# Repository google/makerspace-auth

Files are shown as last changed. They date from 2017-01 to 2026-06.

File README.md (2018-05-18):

# Summary

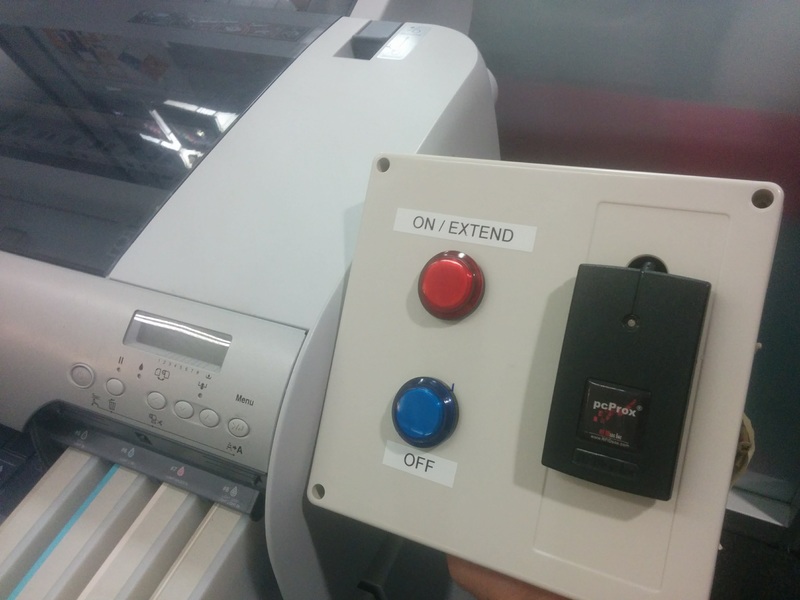
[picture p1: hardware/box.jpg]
Sample controller box


We started this project with two goals in mind, for Google makerspaces where
employees all have the same kind of RFID badge:

1. Only people authorized (trained) should be able to use dangerous tools
2. We'd like to have reliable access logs for even non-dangerous tools

## Organization

    docs/
      Documentation on the project to include contributions on tool connectivity.
    software/
      The Python client that runs on a Pi.
    hardware/
      The custom Pi hat we use to interact with buttons and a power switch tail.

## Contributing

We *welcome* contributions, especially ones that make this more useful to other
makerspaces.  We'd like this to be a generic solution wherever possible.

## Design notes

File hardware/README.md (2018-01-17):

The job of the hardware board is adapt a commodity board to customizable buttons
and actuators.  Currently there is only one board:

## Pi Hat 1
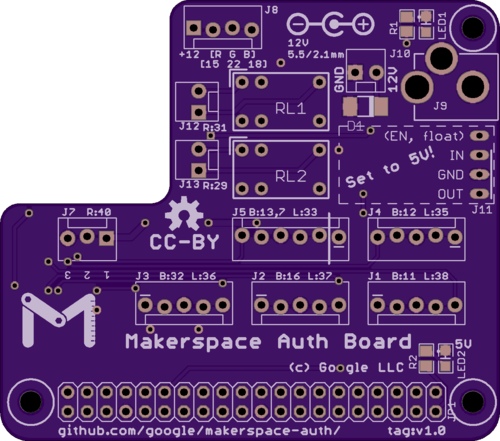
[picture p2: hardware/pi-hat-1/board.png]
Board image


A custom Pi hat which is pretty simple to build (we held intro soldering classes
around it).  The board takes 12V in, powers the Pi under it, and switches 12V
for lights on buttons (up to six of them), a high-current output for external
relays, and two small relays intended for volt-free switching.

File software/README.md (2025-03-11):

# Software

For the basic walkthrough of how this code works, see https://google.github.io/makerspace-auth/client/Walkthrough.html

Prerequisites:

1. Python 2.7 or 3.6+
1. `evdev` (On Raspberry Pi OS, you can install with `sudo apt install python3-evdev`)
1. `gpiozero` module
1. Make sure you're in the 'input' group to use evdev
1. Make sure you're in the gpio group if you're on a Pi

Developing:

1. The easiest way is to run `make setup` and then `. .venv/bin/activate`.
1. You can also run the tests with tox, using `tox -p all`
1. The code is formatted with isort+black, run `make lint` and/or `make format`
   before sending pull requests.

## Protocol

While using a server is optional (you can do everything with shell scripts), we
use a simple HTTP-based protocol that's intended to be easy to adapt to existing
systems. See https://google.github.io/makerspace-auth/server/Protocol.html

## QA example

This simply flashes a light when its button is pressed.  We use this to run QA
on authboards once assembled, and is a very simple example of how the event loop
works.

## Two-button example

We determined two buttons ("on" and "off", basically) to be the minimum viable
controls, and this is the version that we use at Google.  If you're looking for
a good jumping-off point, start here.

The basic workflow is:

1. Scan badge
1. Press "on".  Tool will power up.
1. Warning timer commences beeps.  If you press "on" again, you get more time.
1. Otherwise, tool powers off.

You should copy (or symlink) this file to ~/.authboxrc and make edits to conform
to your pin numbers.  The defaults are for an RDR-6081AKU (keystroking) and
pi-hat-1 v1.0 hardware triggering both onbarod relays to enable devices.

This example out of the box stores authorized users in a local file
(See `sample_auth_check.sh`) but you likely want it to query your existing
user/training database.  If you'd like to use the same protocol, that's
documented at
https://google.github.io/makerspace-auth/server/Protocol.html and if you use
curl, remember the '-f'.

## Starting on boot

The simplest way that works on all distros is a cron job:

    # Visually
    pi$ crontab -e
    (add the following line at the end, save, and apply)
    @reboot cd /path/to/software; python two_button.py

    # Through script
    pi$ (crontab -l; echo "@reboot cd /path/to/software; python two_button.py") | crontab -

If your distro uses systemd, you can also make a systemd unit that runs it.

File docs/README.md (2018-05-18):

## Makerspace Auth

Like most makerspaces, we need to ensure that people have taken training before
using dangerous tools.  This is the Authbox, a project that we're sharing with
the community and welcoming contributions that help it work with more tools.

### Assembling your Authboard 1.0

* [authboard-v1.0/BOM.md](authboard-v1.0/BOM.md)
* [authboard-v1.0/Soldering.md](authboard-v1.0/Soldering.md)

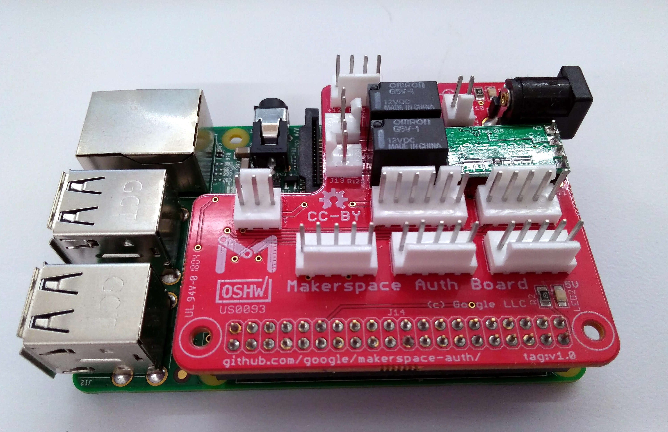
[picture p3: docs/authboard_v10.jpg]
Authboard


### Connecting tools

* [tool-connection/epilog\_mini\_24/](tool-connection/epilog_mini_24)
* [tool-connection/bofa\_ad\_base\_1\_oracle/](tool-connection/bofa_ad_base_1_oracle)

### Connecting to servers

* [server/Protocol.md](server/Protocol.md)

### Client software

* [client/Walkthrough.md](client/Walkthrough.md)

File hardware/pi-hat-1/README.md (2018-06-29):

# Pi Hat 1

This is an example board that fits a Raspberry Pi.  We tried to make it fun
enough to assemble as a beginning soldering exercise (yes, even with surface
mount!), and not use anything too strange.

Board image

## Part notes

The odd board shape is to preserve easy access to CSI bus in case you're using
a camera.

We tested with 2x20 headers both cheap (eBay) and expensive
(SFH11-PBPC-D20-ST-BK at $1.97).  All fit, barely clearing the holes.

The top hole is intended as mechanical joining, but as in all Pi hats, needs an
odd size standoff (M2.5 x 11mm).

You don't need both the 2-pin and barrel supply (in fact, don't power both
simultaneously), but having the second set of pads makes probing easier.

The resistor network can be bussed or independent, either will work.  10k
appears sufficient to overpower the onboard pulldown on boot, but 4.7k (less
common) works too.

## Pinouts

The button pinout is (left-to-right with the tab facing down) is (``IN, n/c,
GND, +12V, Switched GND``).  It's intended for a light and/or button per
connector.  Arcade buttons work fairly well if your enclosure is big enough.

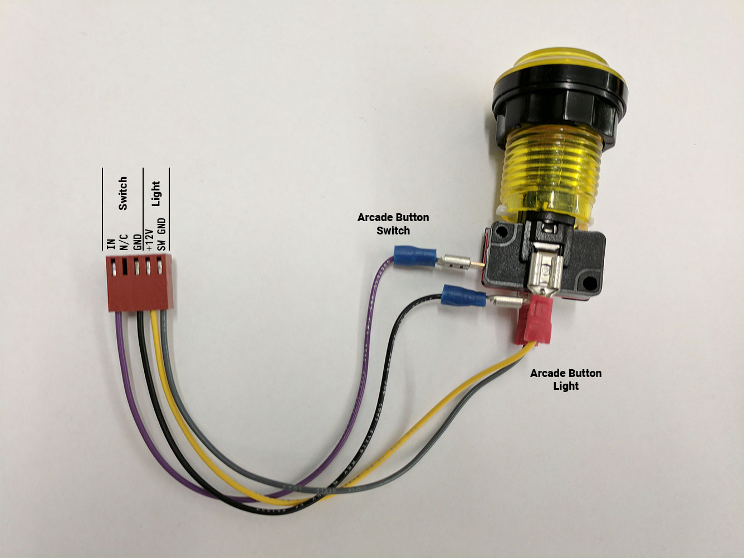
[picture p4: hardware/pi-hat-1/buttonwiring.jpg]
Connector image


The only connector with a freewheeling diode is the 3-pin one marked high current.  It's intended for relay or solenoid use, like for a door.  It's fairly easy to blow the driver chip on all the others.

You can crimp or solder the switch and light side; you should crimp the Molex KK side.

## The 30-second guide to crimping Molex KK

The best tool is Molex 63811-8200, but it's very expensive (350 USD).  We used a budget crimper SN-2549 (23 USD) for these photos, which is the cheapest we've tried that does OK.

For a walkthrough of this process, University of Manchester has produced a video which details the workflow:  [https://www.youtube.com/watch?v=8jcfD1UW8SE](https://www.youtube.com/watch?v=8jcfD1UW8SE)

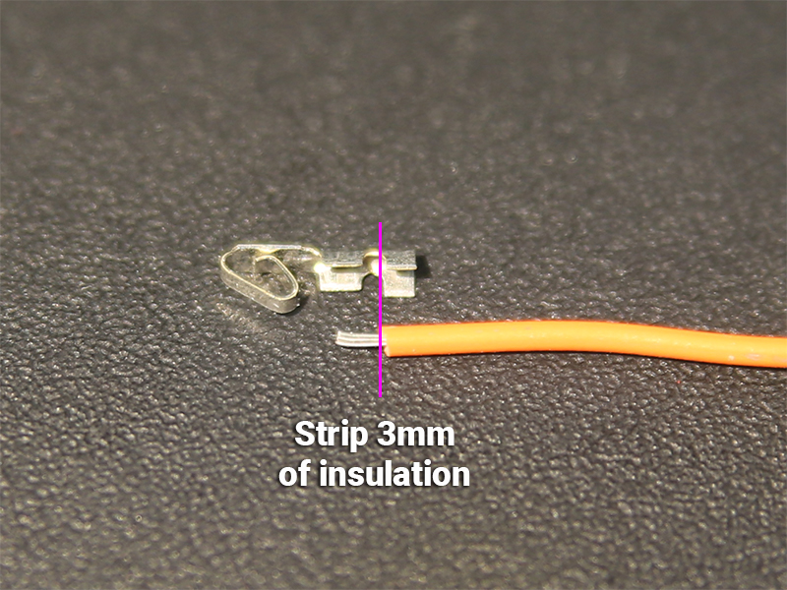
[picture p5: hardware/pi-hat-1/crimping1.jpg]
Crimping Fig. 1

1. Strip 3mm of wire.

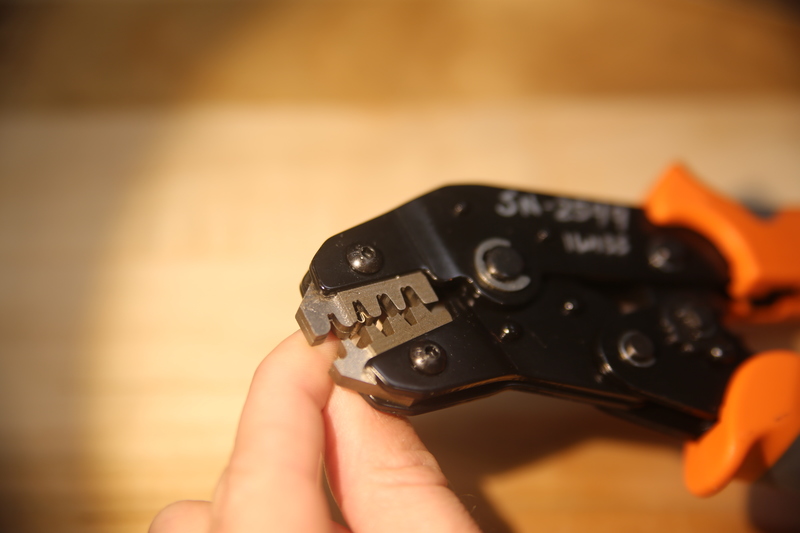
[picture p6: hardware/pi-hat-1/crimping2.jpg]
Crimping Fig. 2

2. Insert into crimper with the open end facing you.

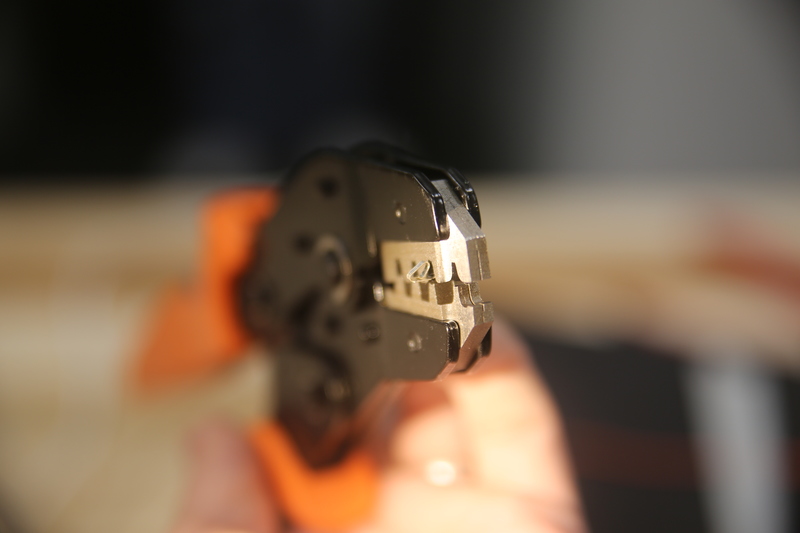
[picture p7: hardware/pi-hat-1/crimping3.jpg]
Crimping Fig. 3

3. Don't crush the spring, which is on the back side, while you close a couple of clicks.  Now insert wire from the front and complete the cycle.

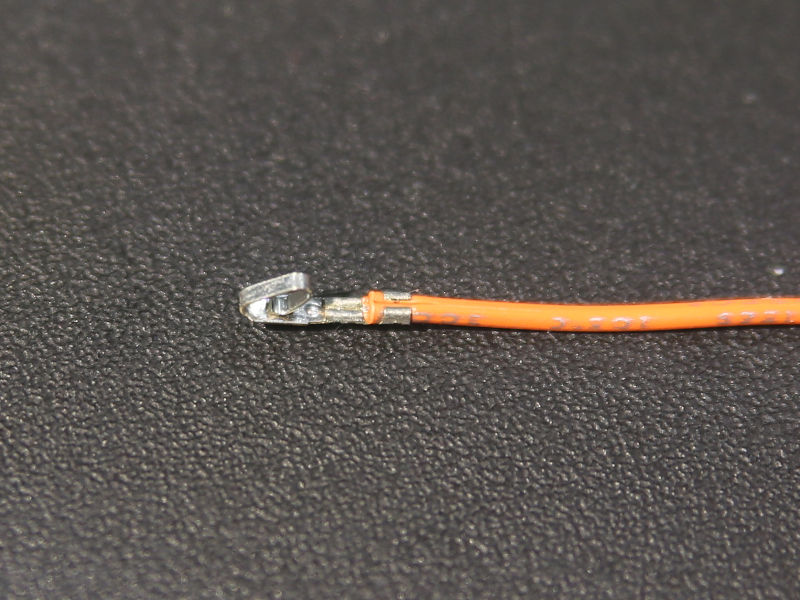
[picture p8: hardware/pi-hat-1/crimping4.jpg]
Crimping Fig. 4

4. This is acceptably crimped.  It's not ideal, but acceptable.

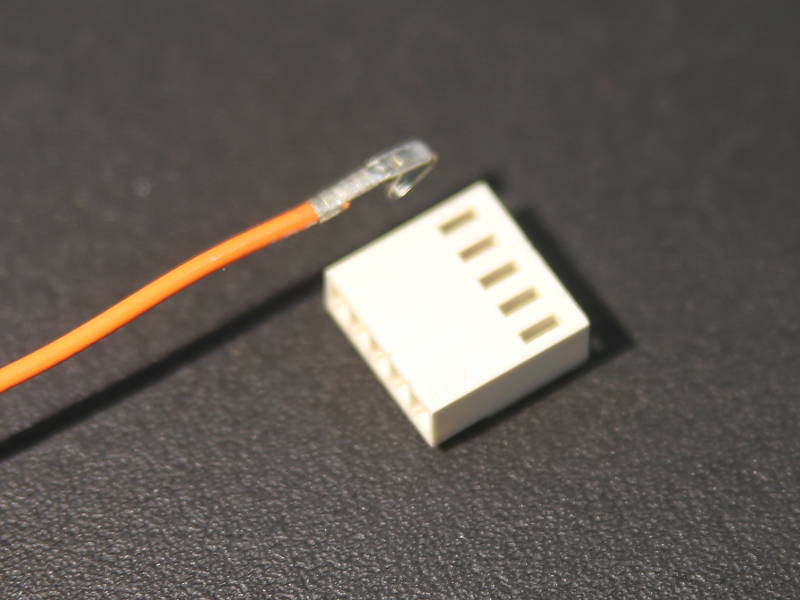
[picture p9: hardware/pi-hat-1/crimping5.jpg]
Crimping Fig. 5

5. Insert into housing with tiny tooth up, and the spring down in this orientation.  It should lock.

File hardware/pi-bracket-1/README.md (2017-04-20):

This holder fits the hole pattern found on a common unbranded 190x185x100mm box, such as https://www.amazon.com/dp/B00UBX0XH6

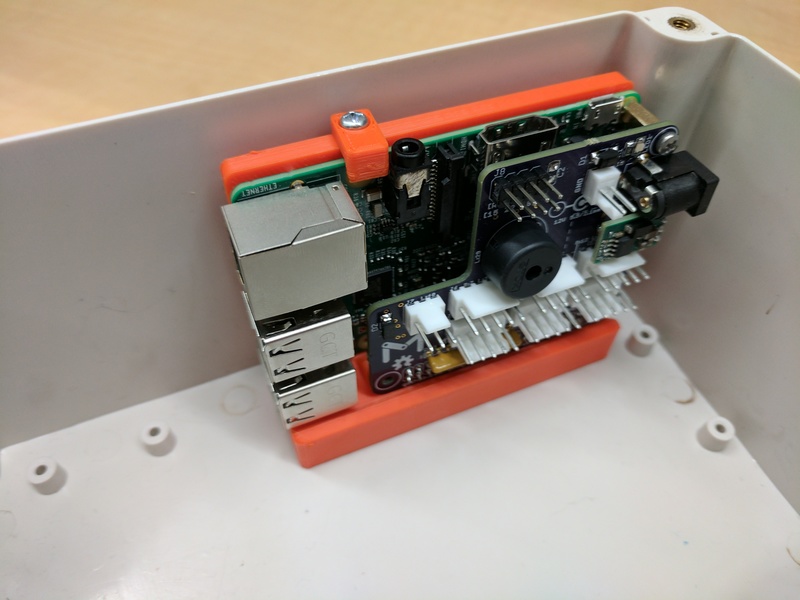
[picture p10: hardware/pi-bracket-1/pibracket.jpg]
Pi Bracket


Source at
https://cad.onshape.com/documents/05d5fe3c5ee63c03d087e8e2/w/24837917d2c22fd129fda85b/e/478f29442292e5ba2817433a (version V1)

Assembly requires:

3x or 4x KA30x8 screws (#4x1/4" is close, but beware of stripping the threads)
1x M2.5x11 threaded standoff
2x M2.5x6 machine screws

We typically print the bracket on its largest flat face.

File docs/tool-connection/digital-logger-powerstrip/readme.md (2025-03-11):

In order to add support for the Digital Loggers IoT relay (https://www.digital-loggers.com/iotfaqs.html), make the following changes:

1: Attach the positive lead to pin 1 of J7 (the pin closest to the J12/J13 relays) and the negative lead to J7 pin 2.

2: Update the software/two_button.ini config file so that the default line 39 now reads " enable_output = Relay:ActiveHigh:40 ".

3: Verify pins 1 and 2 alternate from 12v to 0v with a multimeter, as you actuate the buttons.

Note: Other ports may be workable as well, depending on what you have attached to your hat. Look at hardware/pi-hat-1/ms_auth_breakout.pdf for the full trace. 
J7 is the simplest (the high current relay, ~1A at 12V), but J1-5 may be workable as well (using pin 4 and pin 1 for BN_Logic as a relay). This is untested.
In a pinch, J8 may also work if you're not using an RGB light. 

Note that J12/13 do not work, as they are the volt free switches and the IoT relay expects a 3-60V DC signal.

Also note that polarity matters, so be sure you're sending +12V to the IoT relay.

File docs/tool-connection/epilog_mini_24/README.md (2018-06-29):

## Mini 24 Connection

There are quite a few subcomponents here, but the gist of it is we interrupt the
front door interlock unless you've successfully badged in.

### Mounting plates

Cut these out of 6mm MDF or acrylic.  You'll need the following parts to attach
your box:

 

* [inner plate](plates/one_box_mount_inner.svg)
* [outer plate](plates/one_box_mount_outer.svg)

| Item | Qty |
| --- | --- |
| M4x14 | 8 |
| M4 nut | 8 |
| M4 (fender) washer | 8 |
| #8-32 x 7/8" or 1" | 2 |

In a pinch you can switch #8 to be M4... but either you have to get the length
perfect or be at peace with the holes being re-threaded.

### Box

This is built around a 188x193mm box that you can get
[on Amazon](https://www.amazon.com/gp/product/B0725ZQFJW) or
[Aliexpress](https://www.aliexpress.com/wholesale?SearchText=waterproof+192*188*100mm).
There's plenty of room for activities in this.

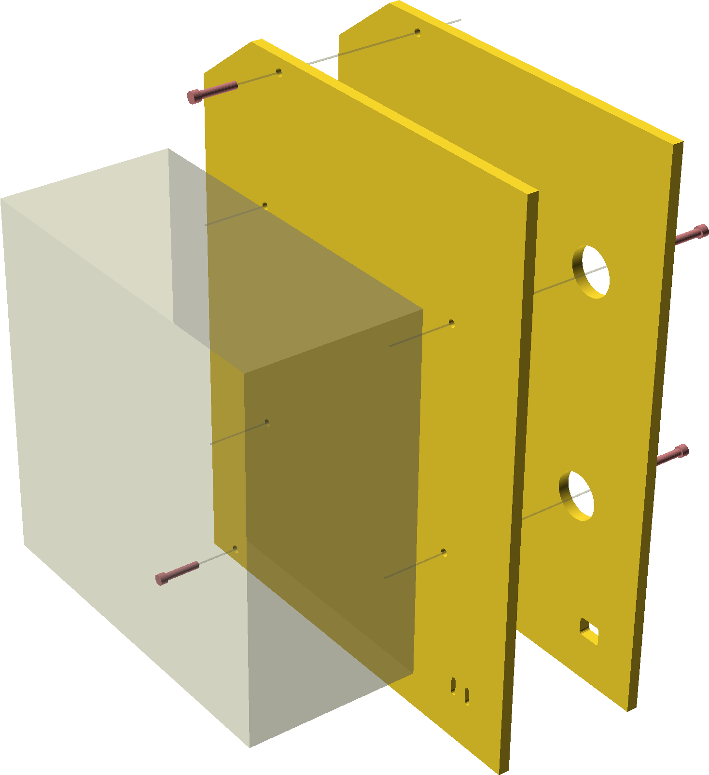
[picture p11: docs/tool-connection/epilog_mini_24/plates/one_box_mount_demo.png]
exploded view


You need to drill 4 holes in the back, and some holes in the sides.  See the
hole template for details (place it on the *back* of the box, and make sure it's
in the correct orientation).



* [hole template](plates/one_box_mount_hole_template.svg)
* [lid hole template](plates/one_box_mount_lid_hole_template.svg)
* [side hole template](plates/one_box_mount_front_hole_template.svg)

### 3D-printed shelf

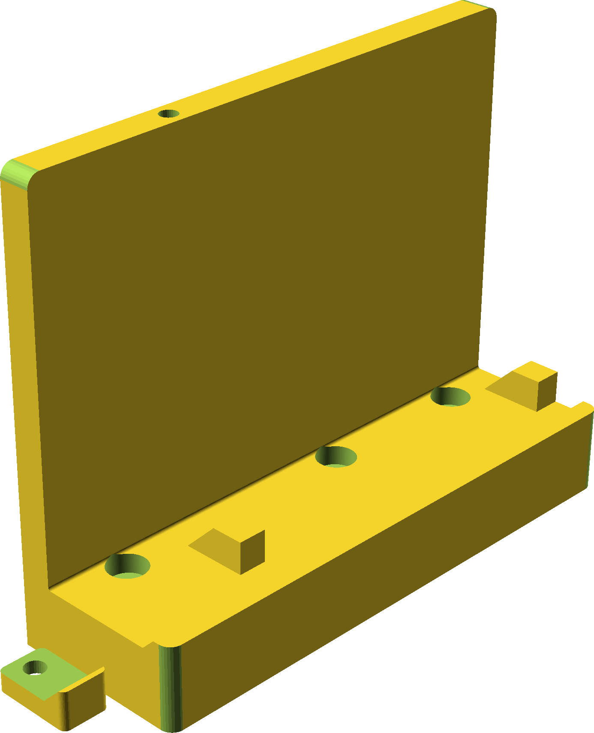
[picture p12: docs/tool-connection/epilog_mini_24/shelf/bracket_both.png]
 

* [bracket+clip](shelf/bracket_both.stl)
* [bracket](shelf/bracket_main.stl)
* [clip](shelf/bracket_clip.stl)

### Power harness

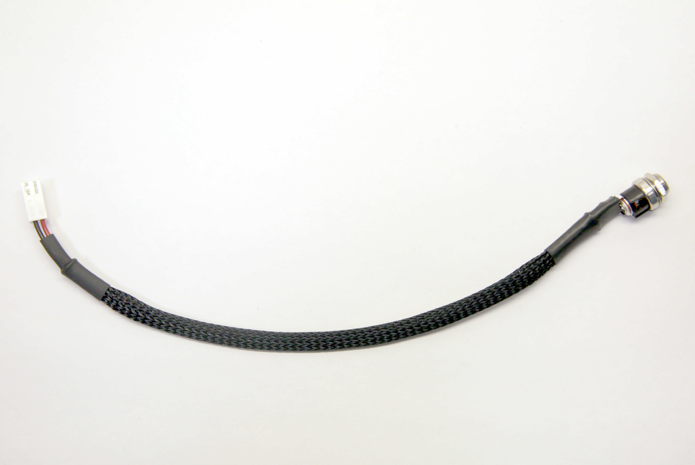
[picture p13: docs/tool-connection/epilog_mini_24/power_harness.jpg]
harness


| Item | Qty |
| --- | --- |
| EJ501A jack | 1 |
| 24 AWG red stranded, 21cm long | 1 |
| 24 AWG black stranded, 21cm long | 1 |
| 18cm sleeving | 1 |
| 25mm 1/4" heat shrink  | 1 |
| 25mm 3/16" heat shrink | 1 |
| 12mm 1/8" heat shrink  | 2 |
| KK pin | 2 |
| KK 2p housing | 1 |

Note the center is typically positive (red).

### Button harness

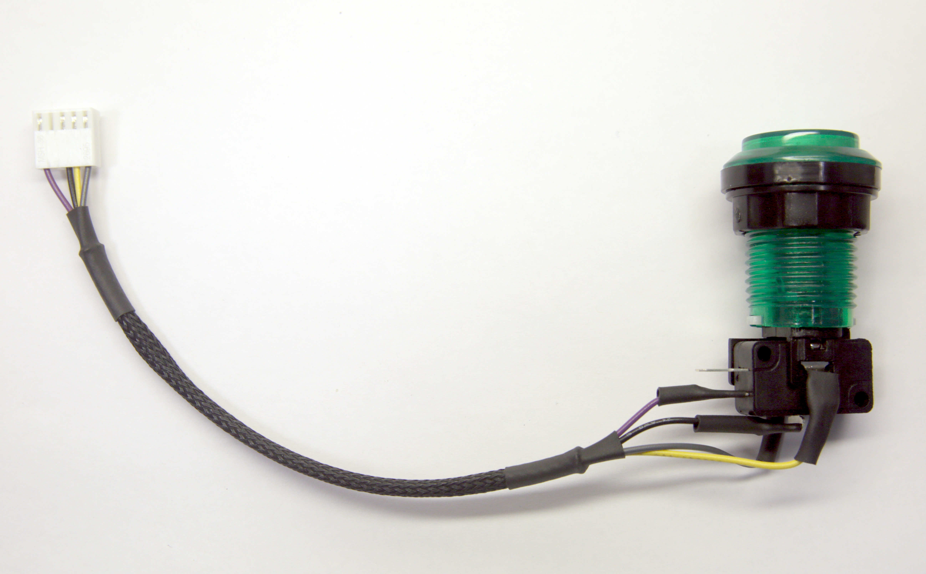
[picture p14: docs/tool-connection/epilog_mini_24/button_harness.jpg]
harness


| Item | Qty |
| --- | --- |
| Arcade button | 1 |
| 24 AWG purple stranded, 20cm long | 1 |
| 24 AWG black stranded, 20cm long | 1 |
| 24 AWG yellow stranded, 21cm long | 1 |
| 24 AWG gray stranded, 21cm long | 1 |
| 12.5cm sleeving | 1 |
| 25mm 3/16" heat shrink | 2 |
| 12mm 3/16" heat shrink | 4 or 5 |
| KK pin | 4 |
| KK 5p housing | 1 |

### Epilog harness

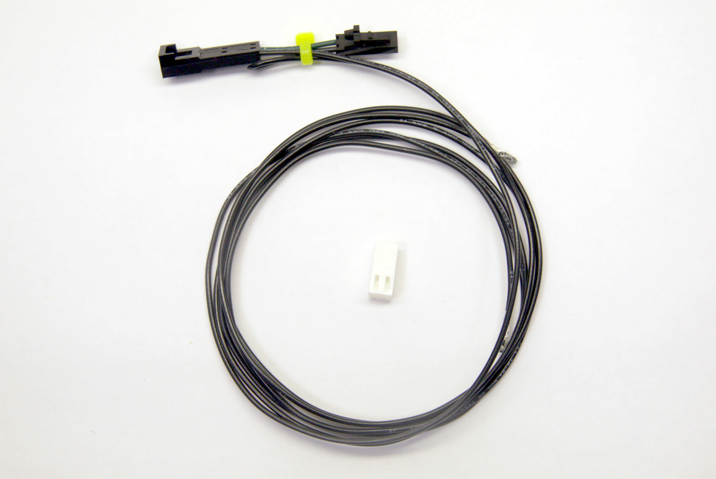
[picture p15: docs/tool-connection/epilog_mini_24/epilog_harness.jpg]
harness


| Item | Qty |
| --- | --- |
| 24 AWG black stranded, 80cm long | 1 |
| 24 AWG black stranded, 82cm long | 1 |
| 24 AWG green stranded, 3cm long  | 1 |
| SL female pin | 2 |
| SL 2p female housing | 1 |
| SL male pin | 2 |
| SL 2p male housing | 1 |
| KK pin | 2 |
| KK 2p housing | 1 |
| small ziptie | 1 |

Note the KK housing is installed after routing through a hole at the bottom of
the machine.  When crimping the M-F on green, the pins should be 180 deg out of
phase in order for the clips to line up like the photo.

### On BOFA

If you're installing this above a BOFA filter, you should move the feet over to
prevent slipping.  3 feet are easy, but the right front foot has a nut on the
inside.  Remove right panel to access.

Once feet are removed, there are other holes about 4" closer to the middle that have
the same thread.

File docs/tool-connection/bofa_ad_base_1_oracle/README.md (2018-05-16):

## BOFA AD Base 1 Oracle Connection

The easiest way to drive this is volt-free from J12 or J13.  Otherwise you can
use 12V from any of the buttons or J7, but check polarity.

## Volt-free input

| Item | Qty |
| --- | --- |
| #24 wire 2 cond x 330cm (McMaster 9290T31)| 1 |
| 25mm 3/16" heat shrink | 2 |
| white ferrules | 2 |
| KK pin | 2 |
| KK 2p housing | 1 |
| Black zip tie | 10 |

Remove power.  Open door using T20 torx driver.  (These screws are captive, but
difficult to get started when you close it up again.)

Remove knockout on back of machine near power switch.  Feed ferrule side of
cable though.  Follow existing wire path in corner of machine up through the
door.

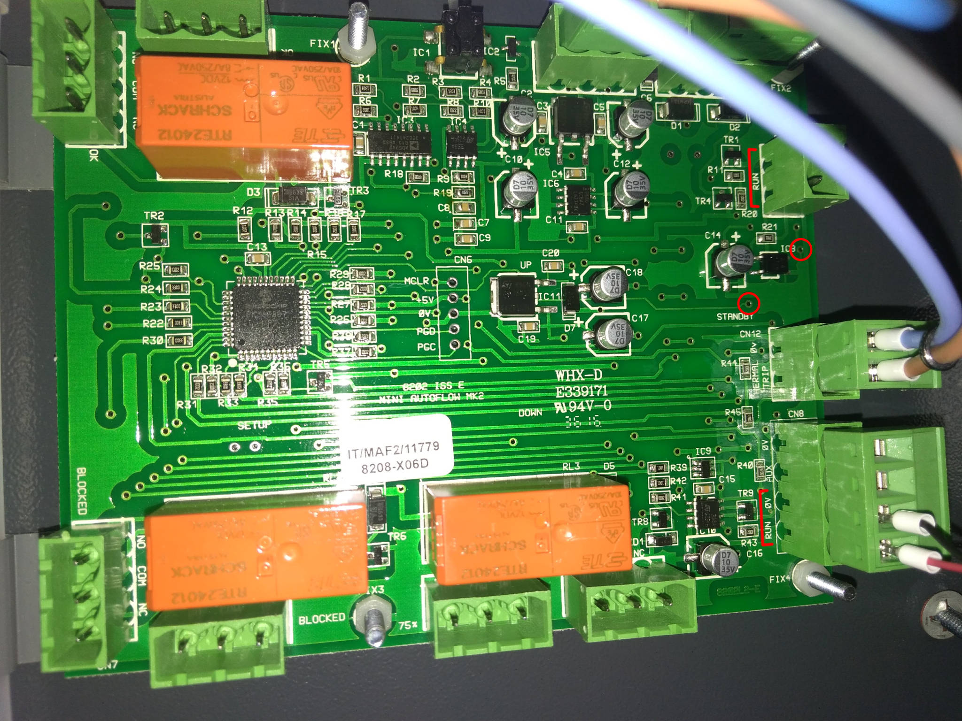
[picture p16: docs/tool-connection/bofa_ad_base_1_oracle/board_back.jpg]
back


Marked with lines in the photo above, there are two Phoenix blocks on the right
side of the circuit board both labeled "RUN".  The one on the 4-pin block ships
with a red jumper wire.  Remove that jumper wire and screw the ferrule end
instead.  (Polarity does not matter.)

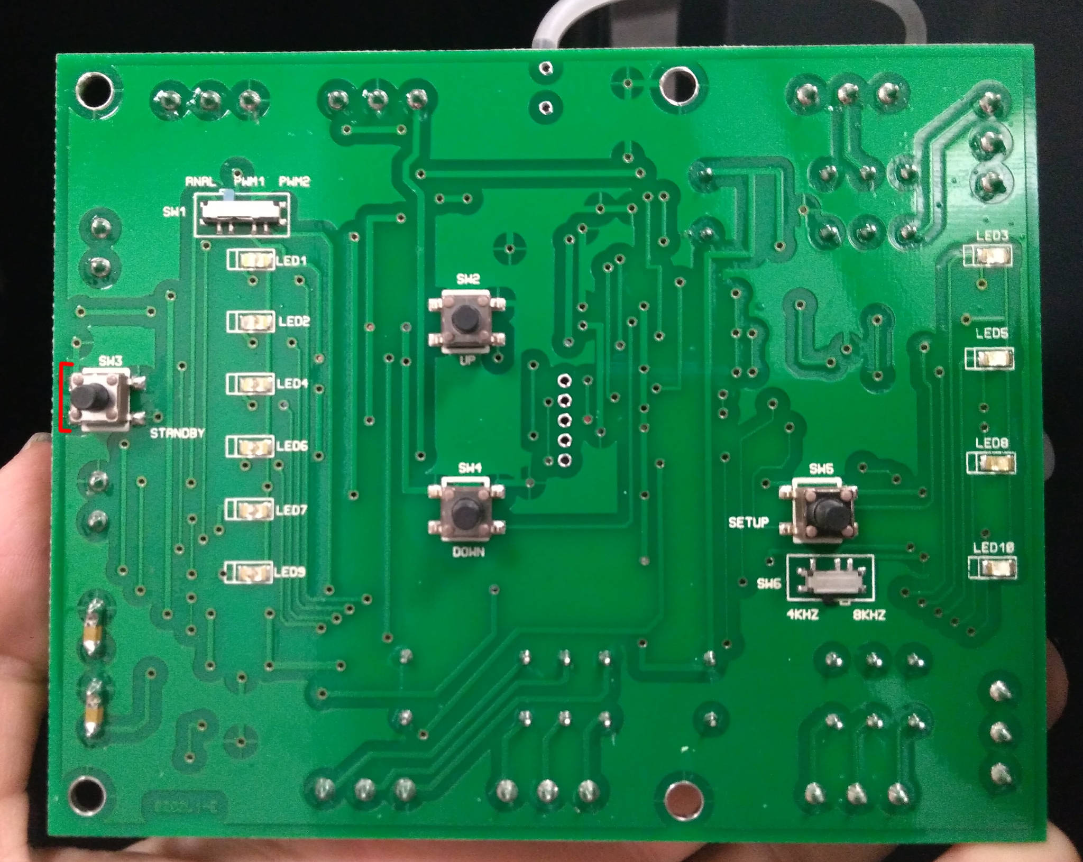
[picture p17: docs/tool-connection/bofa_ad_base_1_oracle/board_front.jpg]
front


Remove the board and solder a small piece of wire across the standby switch
(SW3), or between the nearby vias from back (above text "STANDBY" and to the
right of text "IC8", marked with circles in the first photo above).

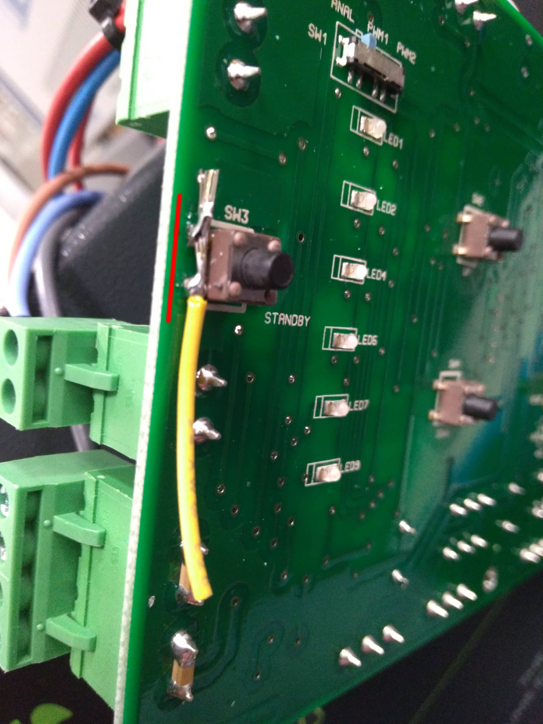
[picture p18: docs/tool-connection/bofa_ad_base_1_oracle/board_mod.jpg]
mod


Once length is right, secure wire along with the existing bundle using zip ties.
On the outside, this cable has a vertical free run, then snakes under the Epilog
behind the rear foot, and through the plate's ziptie mount.

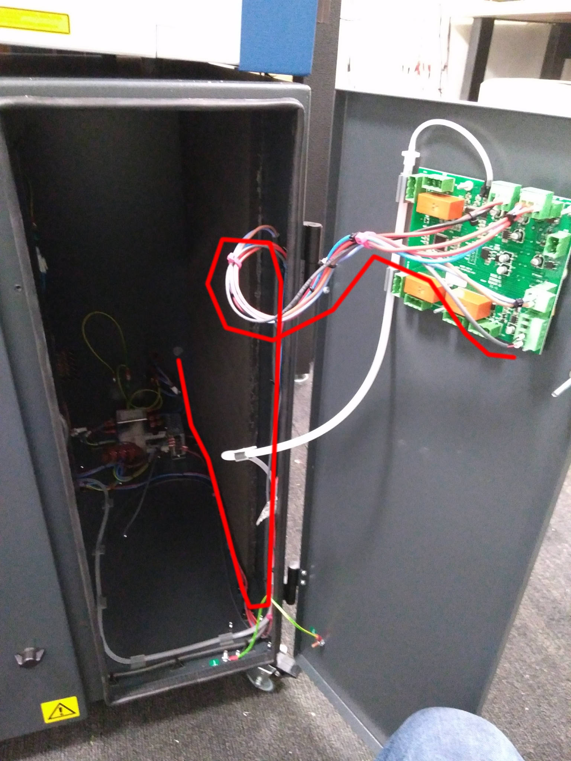
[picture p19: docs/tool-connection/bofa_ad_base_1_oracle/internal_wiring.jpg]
wiring


TODO: Exterior routing diagram.

TODO: Include knockout protector stl with cable clamp.

## 12V Input

Same as above, but you will additionally need

| Item | Qty |
| --- | --- |
| KK 3p housing | 1 |
| 2p Phoenix block | 1 |

Switch to 3-pin KK housing and use on J7 (safest), or 5-pin and use on a button
output (probably ok, assuming BOFA board includes protection diode).  Install
this in the 2-pin RUN, and mind polarity.

## Blocked sensor

There are relay outputs that trigger at 75% or fully blocked.  These are at the
bottom of the board, but we have not experimented with their use.

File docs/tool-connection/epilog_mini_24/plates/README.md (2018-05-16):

## One-box version

Very spacious, plenty of room to add an internal speaker.

Exploded view

| Item | Qty |
| --- | --- |
| M4x14 | 8 |
| M4 nut | 8 |
| M4 (fender) washer | 8 |
| #8-32 x 7/8" or 1" | 2 |

## Two-box version

This version allows you to put a Power Switch Tail in the rear box, while the
front one houses the Pi, buttons, and badge reader.

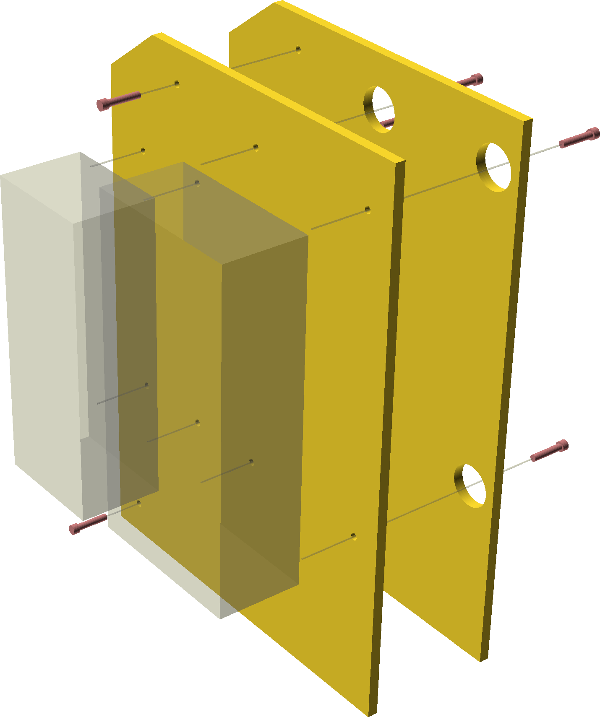
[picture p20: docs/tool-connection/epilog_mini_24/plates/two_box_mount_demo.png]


| Item | Qty |
| --- | --- |
| M4x14 | 4 |
| M4 nut | 4 |
| M4 (fender) washer | 4 |
| #8-32 x 7/8" or 1" | 2 |

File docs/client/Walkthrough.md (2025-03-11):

## Dependencies

* gpiozero
* python evdev

## Loading hardware objects

There's a basic launcher script, e.g. `two_button.py`.  This script should only contain the business logic, and high level interface.

Hardware itself is enabled through the ini file.  For example:

    [pins]
    on_button = Button:11:38

This enables the code in the launcher script to load some number of devices to use as an enabling button (the name is arbitrary):

    class Dispatcher(BaseDispatcher):
      def __init__(self, config):
        super(Dispatcher, self).__init__(config)
        ...
        self.load_config_object('on_button', on_down=self.on_button_down)

Then whenever necessary, you can call

    self.on_button.blink()
    # or
    self.on_button.off()

to change its light, or in

    def on_button_down(self, source):
      print "Button pressed"

## Multiple hardware for one action

Simple! It's a list.

    [pins]
    enable_output = Relay:ActiveHigh:29
    # or
    enable_output = Relay:ActiveHigh:29, Relay:ActiveHigh:31

## Threading model

Each hardware device (button, buzzer, etc) may start its own thread, but events are delivered in one main thread for ease of programming.

## Running on boot

The simplest way is adding an `@reboot cd /path/to/source; python two_button.py` to `crontab -e`.  You can also make a systemd unit, if your distro supports that.

## More reading

See `qa.py` or `two_button.py` for examples of how this can be used.

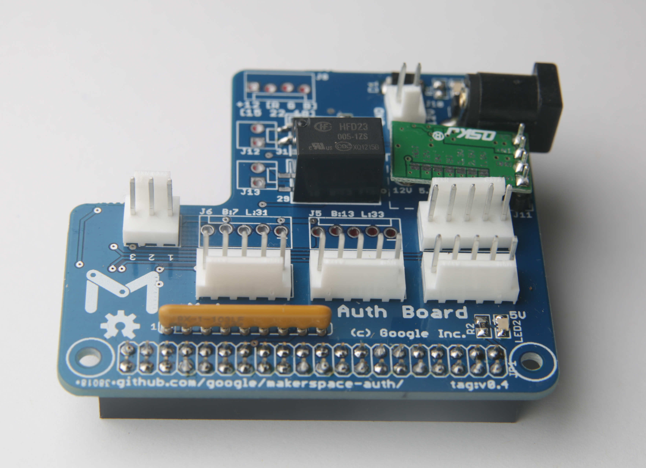
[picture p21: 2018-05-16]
docs/authboard_v04.jpg

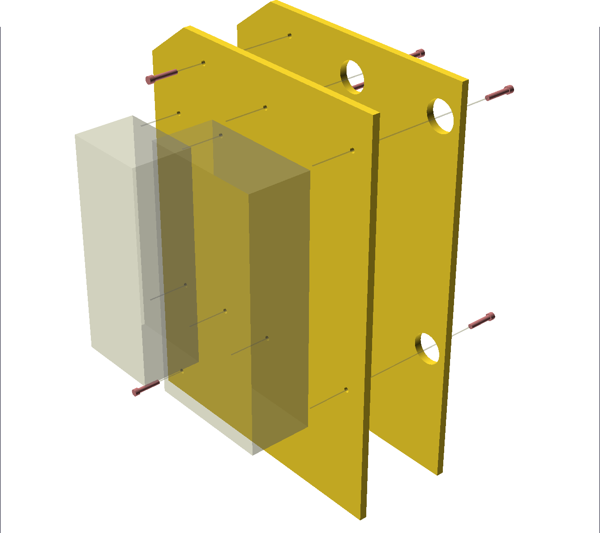
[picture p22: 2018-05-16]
docs/tool-connection/epilog_mini_24/plates/screenshot.png

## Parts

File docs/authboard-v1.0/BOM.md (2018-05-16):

| Refdes | MFN | MPN | Value |
| --- | --- | --- | ----- |
| C2 | Taiyo Yuden | MK316BBJ476ML-T | 47u |
| D1-D4  | Micro Commercial Co | SS14FL-TP | 1A |
| IC1 | TI | ULN2003ADR |
| J10,J12-J13 | Molex | 22-23-2021 |
| J11 | ? | Buck Module | 5V SJ |
| J14 | Sullins | SFH11-PBPC-D20-ST-BK |
| J1-J4 | Molex | 22-23-2051 |
| J5 | Molex | 22-23-2061 |
| J7 | Molex | 22-23-2031 |
| J8 | Molex | 22-23-2041 |
| J9 | Wurth | 694106301002 |
| LED1-LED2 | LG | LG R971-KN-1 |
| Q1-Q6 | Diodes Incorporated | DMN3023L-7 |
| R1 | Yaego | RC0805JR-071KL |
| R2 | Yaego | RC0805JR-07560RL |
| R3-R6 | Yaego | RC0805JR-0710KL |
| RL1-RL2 | Omron | G5V-1-DC12 |

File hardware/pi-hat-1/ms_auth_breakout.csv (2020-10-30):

Reference | Value | Footprint | Datasheet | MPN | Manufacturer | MFN
J14 | PINHD-2X20 | ms_auth_breakout:2X20 |  | SFH11-PBPC-D20-ST-BK | SULLINS CONN SOL
IC1 | ULN2003AD | ms_auth_breakout:SO16 |  | ULN2003ADR | TEXAS INSTRUMENTS
J10 | CONN_02POLAR_LOCK | ms_auth_breakout:MOLEX-1X2_LOCK |  | 22-23-2021 | MOLEX
D1 | DIODE-DO-214AC | ms_auth_breakout:DO-214AC |  | SS14CT-ND | ON SEMI
LED1 | LED | ms_auth_breakout:CHIPLED_0805 |  | LG R971-KN-1 | OSRAM
LED2 | LED | ms_auth_breakout:CHIPLED_0805 |  | LG R971-KN-1 | OSRAM
R2 | 560 | ms_auth_breakout:R0805
R1 | 1k | ms_auth_breakout:R0805
J1 | CONN_05POLAR_LOCK | ms_auth_breakout:MOLEX-1X5_LOCK |  | 22-23-2051 | MOLEX
J2 | CONN_05POLAR_LOCK | ms_auth_breakout:MOLEX-1X5_LOCK |  | 22-23-2051 | MOLEX
J3 | CONN_05POLAR_LOCK | ms_auth_breakout:MOLEX-1X5_LOCK |  | 22-23-2051 | MOLEX
J4 | CONN_05POLAR_LOCK | ms_auth_breakout:MOLEX-1X5_LOCK |  | 22-23-2051 | MOLEX
J7 | CONN_03POLAR_LOCK | ms_auth_breakout:MOLEX-1X3_LOCK |  | 22-23-2031 | MOLEX
J9 | POWER_JACKPTH_LOCK | ms_auth_breakout:POWER_JACK_PTH_LOCK |  | 694106301002 | WURTH EL
C2 | 47u | ms_auth_breakout:C1206
U$1 | MS_LOGO | ms_auth_breakout:MS_LOGO_VECTOR
Q1 | DMN3023L | ms_auth_breakout:SOT23-3 |  | DMN3023L-7 | DIODES INC
Q2 | DMN3023L | ms_auth_breakout:SOT23-3 |  | DMN3023L-7 | DIODES INC
Q3 | DMN3023L | ms_auth_breakout:SOT23-3 |  | DMN3023L-7 | DIODES INC
Q4 | DMN3023L | ms_auth_breakout:SOT23-3 |  | DMN3023L-7 | DIODES INC
LOGO1 | OSHW-LOGOM | ms_auth_breakout:OSHW-LOGO-M
Q5 | DMN3023L | ms_auth_breakout:SOT23-3 |  | DMN3023L-7 | DIODES INC
Q6 | DMN3023L | ms_auth_breakout:SOT23-3 |  | DMN3023L-7 | DIODES INC
RL1 | HFD23_SPDT | ms_auth_breakout:HFD23 |  | HFD23/012-1ZS | HONGFA | HF
RL2 | HFD23_SPDT | ms_auth_breakout:HFD23 |  | HFD23/012-1ZS | HONGFA | HF
J13 | CONN_02POLAR_LOCK | ms_auth_breakout:MOLEX-1X2_LOCK |  | 22-23-2021 | MOLEX
J12 | CONN_02POLAR_LOCK | ms_auth_breakout:MOLEX-1X2_LOCK |  | 22-23-2021 | MOLEX
J8 | CONN_04POLAR_LOCK | ms_auth_breakout:MOLEX-1X4_LOCK |  | 22-23-2041 | MOLEX
D2 | DIODE-DO-214AC | ms_auth_breakout:DO-214AC |  | SS14CT-ND | ON SEMI
D3 | DIODE-DO-214AC | ms_auth_breakout:DO-214AC |  | SS14CT-ND | ON SEMI
D4 | DIODE-DO-214AC | ms_auth_breakout:DO-214AC |  | SS14CT-ND | ON SEMI
R3 | 10k | ms_auth_breakout:R0805
R4 | 10k | ms_auth_breakout:R0805
R5 | 10k | ms_auth_breakout:R0805
R6 | 10k | ms_auth_breakout:R0805
J5 | CONN_06POLAR_LOCK | ms_auth_breakout:MOLEX-1X6_LOCK |  | 22-23-2061 | MOLEX
U$2 | US0093 | ms_auth_breakout:CERT-SMALL-SILK
J11 | BUCK_MODULEHORIZONTAL | ms_auth_breakout:BUCK_HORIZONTAL |  | mp2315-module | Proto supplies

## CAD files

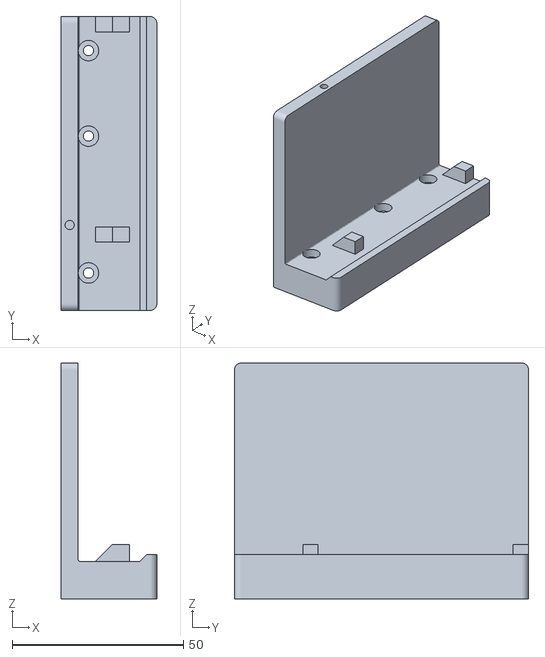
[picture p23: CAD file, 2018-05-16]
docs/tool-connection/epilog_mini_24/shelf/bracket_main.stl
28.0 x 86.0 x 69.0

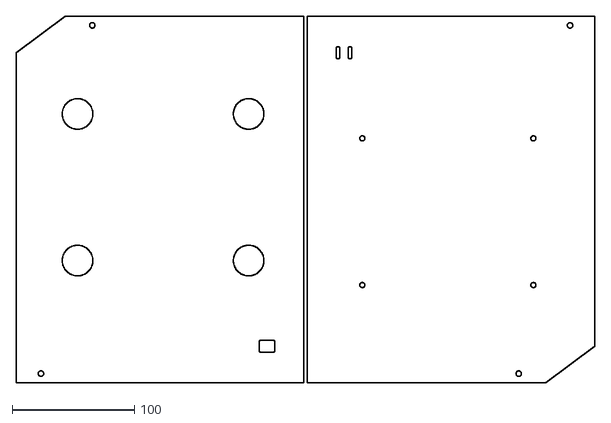
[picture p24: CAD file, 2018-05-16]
docs/tool-connection/epilog_mini_24/plates/one_box_mount_both.dxf
473.0 x 300.0

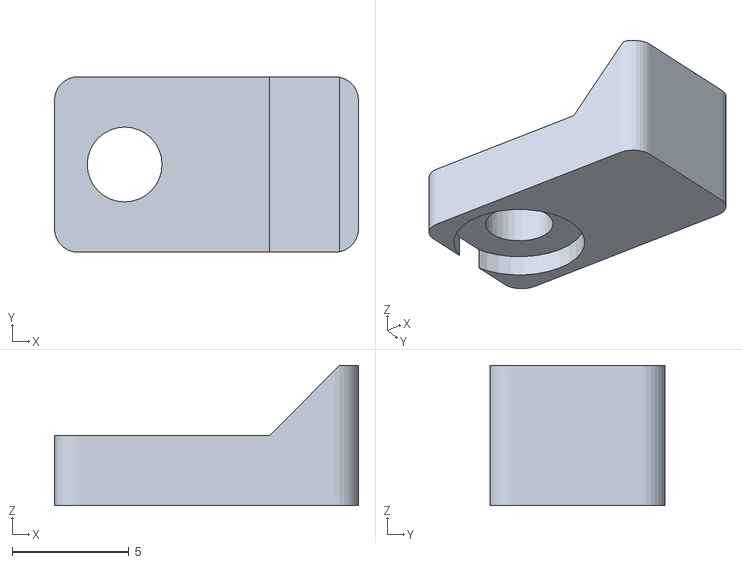
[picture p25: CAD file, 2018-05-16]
docs/tool-connection/epilog_mini_24/shelf/bracket_clip.stl
13.0 x 7.50 x 6.00

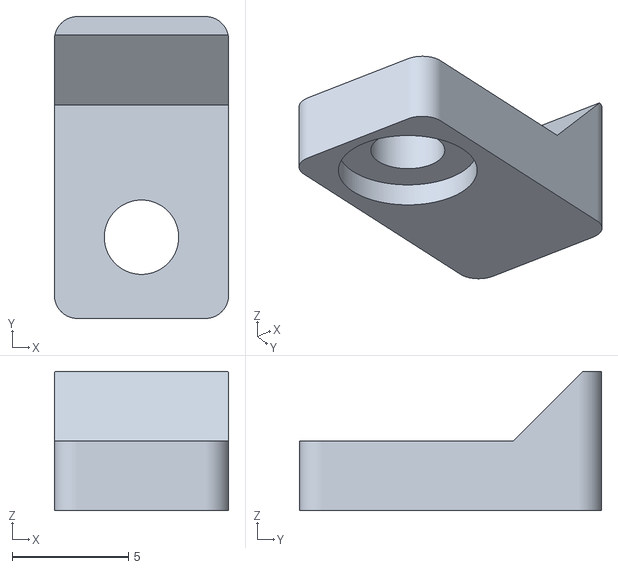
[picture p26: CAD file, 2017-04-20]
hardware/pi-bracket-1/piclip.stl
7.50 x 13.0 x 6.00

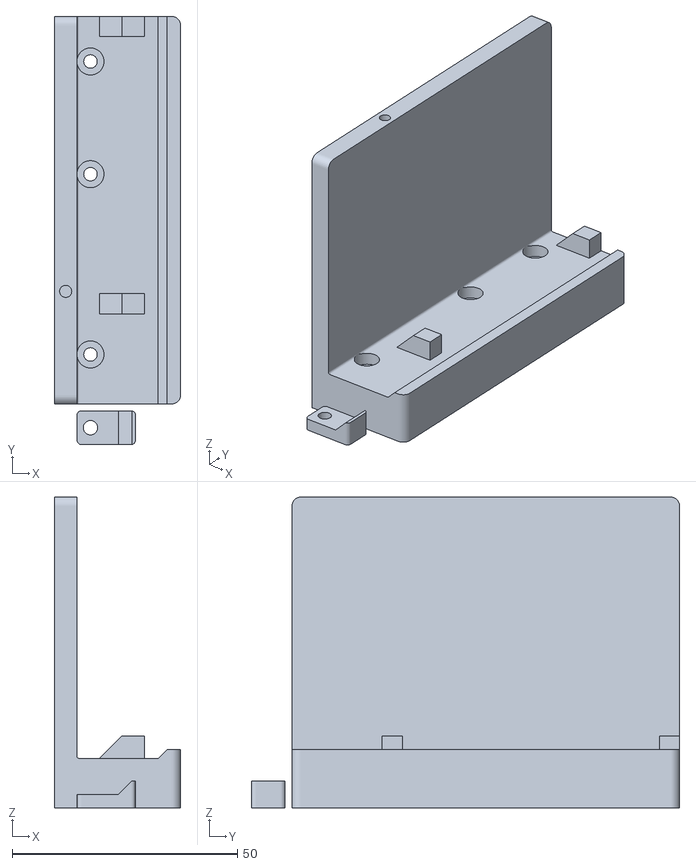
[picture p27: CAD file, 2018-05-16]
docs/tool-connection/epilog_mini_24/shelf/bracket_both.stl
28.0 x 95.0 x 69.0

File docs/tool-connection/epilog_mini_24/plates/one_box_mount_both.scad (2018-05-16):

include <one_box_mount_lib.scad>

Inner();
translate([plate_width*2+3,plate_height]) rotate([0,0,180]) Outer();

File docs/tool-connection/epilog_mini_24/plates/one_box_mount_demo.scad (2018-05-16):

include <one_box_mount_lib.scad>
rotate([90,0,0]) Exploded();

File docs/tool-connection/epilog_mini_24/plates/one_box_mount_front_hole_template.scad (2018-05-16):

include <one_box_mount_lib.scad>
FrontHoleTemplate();
translate([120,0]) BackHoleTemplate();

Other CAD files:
hardware/pi-bracket-1/pibracket.stl
docs/tool-connection/epilog_mini_24/plates/one_box_mount_hole_template.scad
docs/tool-connection/epilog_mini_24/plates/one_box_mount_inner.scad
docs/tool-connection/epilog_mini_24/plates/one_box_mount_lib.scad
docs/tool-connection/epilog_mini_24/plates/one_box_mount_lid_hole_template.scad
docs/tool-connection/epilog_mini_24/plates/one_box_mount_outer.scad
docs/tool-connection/epilog_mini_24/plates/two_box_mount_demo.scad
docs/tool-connection/epilog_mini_24/plates/two_box_mount_inner.scad
docs/tool-connection/epilog_mini_24/plates/two_box_mount_lib.scad
docs/tool-connection/epilog_mini_24/plates/two_box_mount_outer.scad
docs/tool-connection/epilog_mini_24/shelf/bracket_both.scad
docs/tool-connection/epilog_mini_24/shelf/bracket_clip.scad
docs/tool-connection/epilog_mini_24/shelf/bracket_lib.scad
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

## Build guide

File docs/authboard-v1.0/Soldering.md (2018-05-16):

## General Assembly

This involves a good amount of SMT soldering.  If you've never done it before, watch [this video](https://www.youtube.com/watch?v=_kNTFCuy4xk) I threw together.  The first rule I'll give you with is that any pin can take 2 seconds of heat without damage at normal temperatures (up to 700 deg F).  More than that is at your own risk.  The second is that generally the numbers on these parts face up.

The parts that might burn out due to overcurrent are on the bottom of the board -- worse for automated assembly, much better for replacing after a failure.  I'd suggest roughly this order of assembly:

* R1, LED1 (touch with a bench supply to GND, 12V and confirm light)
* R2, LED2 (touch with a bench supply to GND, OUT and confirm light)
* D1, D2, C2 

Take a break.  You're done with the top-side 2-pin SMT.

* R3-R6 (bottom side)
* IC1, bottom side observing polarity (for the most clearance, this is first).
* Q1-Q6, bottom side
* JP1 (40-pin header, which is inserted from bottom side and soldered on top). No keying on the Raspbery Pi GPIOs so it doesn't matter which way you place this.

Take another break.

* J11 (buck module) with ADJ trace cut and 5V solder jumper closed.  Install and test without a Pi, and with a bench supply at 12V: You should get 5V on output and not hit a 100mA current limit.
* Remaining J connectors, being careful that they are installed straight.

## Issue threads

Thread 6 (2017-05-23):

Fix piezo footprint

thatch, 2017-05-23:
The spacing on the pins isn't right for the part on the BOM; also lacks a resistor or some other driver since it's not self-oscillating.

thatch, 2018-05-18:
This is offboard now, but still need to document.

thatch, 2019-06-10:
I used https://www.amazon.com/gp/product/B00W8YCCXO/ but I don't remember if the standard build is on the 3-pin power switch tail output or one of the 5-pin connectors.  @cunninghamsandwich can you get a picture of the standard build and put that in the repo?

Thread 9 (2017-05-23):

Board: Make the hardware cheaper

thatch, 2017-05-23:
I've been kicking around an idea for an ESP8266 board with fewer buttons.

ParthenonTech, 2018-08-07:
Would love that.  I'm wondering if this version or an upcoming one might work on a Pi Zero, too.

thatch, 2018-08-10:
@ParthenonTech This version should work just fine on a Pi Zero (although the 3rd mounting hole will be in open air, so you might want a 3d printed bracket).  I don't think it would shrink well down to that side without removing some features (and the enclosure still pretty much dominates the cost).  Do you have more info on your application, about what tool and mounting you want?

ParthenonTech, 2018-08-10:
I wasn't thinking about the size, just the BOM cost.  Anything to make it a no-brainer to attach one to just about anything in the makerspace that requires training.

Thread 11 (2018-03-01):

C2 capacitor sizing

brianredbeard, 2018-03-01:
The C2 filter capacitor is specified by part number [C3216JB1E476M160AC](https://www.digikey.com/product-detail/en/tdk-corporation/C3216JB1E476M160AC/445-11717-1-ND/3953383) is flagged by the manfucaturer "Not for use in new designs".

For a ceramic capacitor of that high of a voltage/capacitance it seems that its a pretty niche part.

Sticking in a 1206 footprint it appears that one can go as high as 33µF when sticking to 12v or 47µF if the voltage can drop to 10v.

Are there any suggestions for replacement parts?

thatch, 2018-03-01:
My last build used EMK316BBJ476ML-T but that's out of stock at both digikey and mouser now too.

Originally, I was intending to PWM the LEDs, and included C2 defensively to cope with switching currents on underpowered power supplies... but driving with a nice power supply and slow output changes empirically works fine without C2.

Happy to answer other questions as well.

brianredbeard, 2018-05-20:
Understood.  I think this documentation sufficient for the time being to close the issue out.

Closed 2018-05-20.

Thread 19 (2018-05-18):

v1.0 Errata: R5 Removal

thatch, 2018-05-18:
## Background

The intention behind J5 was to have two input pins to support a 3-position switch using software-configurable pullups (B5 and B6).  After initial investigation for _outputs_ (called L* in schematic), we determined that physical pin 7 was pulled HIGH on boot, and didn't want relays accidentally triggering before the Python code could start.  The four pins we use that are pulled HIGH in default [device tree](https://www.raspberrypi.org/documentation/configuration/pin-configuration.md), we included a stronger pulldown resistor, regardless of whether they were intended for input or output.

## The problem

The stronger hardware pulldown in tag:v1.0 (R5, 1k) fights with the software pullup (guessing about 5.6k), resulting in a max 0.5V which is still considered LOW.  Looking at the physical boards, this could have been a problem as early as tag:v0.3, but the pulldown was only 10k in my locally-built v0.3 and v0.4 boards.

## Resolution

Desolder R5

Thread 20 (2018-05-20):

Consider migration to Open/Common Parts Library

brianredbeard, 2018-05-20:
When attempting to source the materials for the board as well as collaborate on revisions it would be nice to consider the use of the common parts library.

Pros:
This would allow users to easily access datasheets, compare compatible devices, and check on the life cycle of parts.

Cons:
I personally am not an expert in Eagle so I'm note sure if there are any easy ways to handle updating these devices so this could mean a non-trivial amount of work in swapping parts.

thatch, 2018-07-09:
I took a glance, and some parts would be straightforward to convert after #25 is done.  I would argue that KK (or KF2510) fits our needs better than XH though, thinking about ability to crimp with everyday tools.  It might also be worth experimenting with replacing the driver IC with individual mosfets.

If the list is in active development, would be nice to get AO3400/3401 mosfets, 2x20 female headers, and a through-hole power jack added to it.

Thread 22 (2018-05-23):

Inquiry: Hookup of additional devices

brianredbeard, 2018-05-23:
I''m currently thinking through a personal need as well trying to be a bit more forward thinking.

Originally, I was going to make the suggestion of exposing UART via a 4 pin connector.

Then I realized that the pins for SPI0, I2C, _and_ UART are all unpopulated.  Is there an opinion on whether the strategy is to stack boards, use a pass through header, or potentially expose any of these pins via a header in the future?

thatch, 2018-05-23:
Avoiding those pins was an intentional design choice.  We've had spaces asking about displays in particular since the beginning.

For prototyping, I've tacked bodge wires on the UART pins and I think a stacking header on an intermediate hat would work fine.

Longer term, if you can find the board space to add those headers, go for it and send a PR.  The easiest place is probably where the URL is right now, and expand the board a little.  You could probably also sneak in the serial header where the 5V trace is near J1.

thvortex, 2018-05-23:
Just FYI re: UART.

My understanding is that the default device tree on a Raspberry Pi 3/ Zero
W connects the crappier "mini UART" to those external pins and it uses the
good PL011 UART for Bluetooth (Serial Port Profile?).

Probably the main side effect is that CPU frequency scaling is disabled
when using those external UART pins in the default config. You can apply a
device tree overlay to switch the UART assignment or to disable Bluetooth
outright.

See: https://www.raspberrypi.org/documentation/configuration/uart.md

On Wed, May 23, 2018 at 11:44 AM, Tim Hatch <notifications@github.com>
wrote:

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

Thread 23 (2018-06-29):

Document use of pins to create a "case open" switch.

brianredbeard, 2018-06-29:
Similar to older PC cases, we should evaluate a way to provide feedback to the Raspberry PI to know if the case it is in has been opened.  At the same time, this largely predicates other things like:
  - constant power
  - stable storage

Similarly the "right" way to do this in the world of distributed systems is more along the lines of endpoint monitoring so that you know if/when the endpoint goes offline.

Thoughts?

thatch, 2018-06-29:
Sure!  If there aren't any requirements about shared ground (say, to use an existing switch in a piece of equipment) this is straightforward:

- Hardware, using the switch inputs documented at https://github.com/google/makerspace-auth/tree/master/hardware/pi-hat-1#user-content-pinouts
- Software, using a pullup oin the gpio and reading current state/an interrupt.  If using our framework, the ThreePosSwitch does this in a pretty safe way with bounded delay that doesn't require debouncing, and can be used as a guide.

Were you suggesting this for the tool's case, or the authbox's case?  The box we spec'd doesn't have a good way to mount things near the lid, but we're still looking for something better.

I worry about removing power to the authbox as a way around that; we don't currently have a battery backup.

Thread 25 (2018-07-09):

Convert PCB to KiCad, Tag New Version

thatch, 2018-07-09:
Since starting this board, we've moved most of our effort/libraries/automation to kicad.  We should convert the board to make it more easily to make changes an export the BOM.

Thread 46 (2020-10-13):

Electrical improvements to pi-hat board

thvortex, 2020-10-13:
I've had some ideas about electrical and layout improvements to the pi-hat board:

1. All the empty space on the board should be converted into a ground plane with additional ground traces running in-between the signal traces. One benefit is that less etchant gets consumed during the manufacture process because less copper has to be removed. The other benefit is improved EMI protection. I've heard one anecdotal report that if the authbox is brought close enough to a GAST air pump, the Raspberry Pi may spontaneously reboot. No idea if that was caused by the pi-hat board, but we do have long signal traces that can potentially act as an antenna.

2. Add room for a debouncing capacitor between each Bn_LOGIC line and GND. The board still works without them thanks to the `GPIO.add_event_detect(... bouncetime=150)` we have in software, but that's just a simple delay. If you hold the button down longer than 150ms and release it, it will register as a 2nd press due to bounce caused by opening button contacts. There's no need for separate resistors since we enable internal pull-ups in the Raspberry Pi for the Bn_LOGIC lines.

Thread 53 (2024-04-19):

RPi.GPIO module is unmaintained and incompatible with latest Raspberry Pi OS

The-Bootloader, 2024-04-19:
The software uses the RPi.GPIO module to access the GPIOs. This module seems unmaintained, the last release [0.7.1](https://pypi.org/project/RPi.GPIO/#history) was on Feb 2022.

One [known issue](https://sourceforge.net/p/raspberry-gpio-python/tickets/210/) is that this module uses a deprecated sysfs interface which has been removed in the latest version of Raspberry Pi OS.

This is causing the code to not work anymore on that version, due to ```RuntimeError: Failed to add edge detection```, when the code tries to register an event-driven handler for GPIO changes through that deprecated sysfs interface.

It seems like this interface has been [deprecated since 2015](https://www.thegoodpenguin.co.uk/blog/stop-using-sys-class-gpio-its-deprecated/) and is undergoing a slow death since then. We should migrate away from it ASAP.

Today, it is **still** possible to do an installation by selecting the "Legacy" version of the OS, but, at some point, these changes will trickle down to the Legacy version, and then the code **will not work anymore** on any supported OS version, which will introduce a variety of difficulties for the users, from security vulnerabilities to the unavailability of repositories.

As such, the project needs to start migrating to another GPIO library, or to access the GPIOs in a different way.

One possible option is to use the gpio-key dtoverlay (which will create input devices for each key), and gpio-led dtoverlay (which will create a kernel-level, sysfs-accessible LED device). These options are well supported and modern, but require some changes in the code. Unclear how the buzzer should be accessed, maybe through the audremap dtoverlay (this requires a PCB change and a BOM change, but would allow playing sounds directly instead of just being able to beep).

Another option is to use gpiod, but the dtoverlay approach seems more elegant and flexible.

Either way, this needs to start soon, before users are locked out of using the code in currently supported distributions.

The purpose of this issue is to track progress in this area.

precision, 2024-04-19:
https://github.com/gpiozero/gpiozero/ is another alternative

coffeefueleddiy, 2024-06-14:
Thanks for bringing this up! I looked into dtoverlays and agree that defining the board in this way would be great. (Even more so if we could update the hardware board to be a proper HAT with eeprom specifying the hardware as [discussed here](https://github.com/raspberrypi/hats/blob/master/devicetree-guide.md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). [New tools here.](https://github.com/raspberrypi/utils/tree/master/eeptools))

However, I think we should first update the repo to support modern Raspberry Pi OS with minimal changes.

I have worked on this locally and successfully converted most of the GPIO calls to gpiozero. I have some cleanup to do and then I'll upload it here for further discussion.

edropps, 2024-09-27:
@coffeefueleddiy did you get a chance to clean this up?  Would love to see this get fixed.

coffeefueleddiy, 2024-10-05:
Unfortunately I haven't had much time recently to work on this. However, I believe the main thing I needed to do was fix tests. I'll take another look and either finish it or at least upload it in case someone else has time to take it from its current state.

The-Bootloader, 2024-12-26:
> https://github.com/gpiozero/gpiozero/ is another (almost drop in) alternative

I just tried to use it on an unrelated project and guess what - same problem, it wants to access the deprecated sysfs interface.

```
Traceback (most recent call last):
  File "testproject/env/lib/python3.11/site-packages/gpiozero/pins/native.py", line 247, in export
    result = os.open(self.path_value(pin),
             ^^^^^^^^^^^^^^^^^^^^^^^^^^^^^
FileNotFoundError: [Errno 2] No such file or directory: '/sys/class/gpio/gpio18/value'
```

So unless I am missing something or made some sort of mistake - I recommend not using gpiozero until it is migrated to, or is able to use, the new gpiochip kernel interface

thatch, 2024-12-26:
Looks like it has [several backends](https://github.com/gpiozero/gpiozero/blob/ceaec6150c71654585113320113cb45f0aa784b5/gpiozero/devices.py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), and in your case it chose `native` -- if you want it to use gpiochip you also need `lgpio` installed and it will be preferred automatically.

coffeefueleddiy, 2025-03-01:
I've finally gotten around to update all the tests on [my branch here](https://github.com/coffeefueleddiy/makerspace-auth/tree/gpiozero)!

My next steps are to:

- check (and update as needed) the two test files which rely on evdev on an actual pi
- install on a fresh modern OS pi install and then test two_button.py
- use this branch on a real tool to test it out in a real situation

I hope to get through all these steps in the next week or two.

coffeefueleddiy, 2025-03-02:
I finished the first 2 points above just tested setup with the latest Raspberry Pi OS and the gpiozero branch referenced above works!

Feel free to give it a try and let me know if you hit any issues.

cunninghamsandwich, 2025-03-11:
Verified on a Pi 3 running Raspberry Pi OS Lite (64-bit) [Bookworm], connected to an Epilog Fusion Maker 12.  This is now merged - Thanks for your help!

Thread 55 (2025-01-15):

Modifying to control a power strip via 3v-60v DC signal

bklebke, 2025-01-15:
Hello! Hoping to use this in SFO-SPE to control something like this: https://abra-electronics.com/electromechanical/relays/miscellaneous-en-4/2935-ada-controllable-four-outlet-power-relay-module-version-2-power-switch-tail-alternative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

In my exploration, using J12/J13 doesn't seem to work -- I'm guessing because these are one of the two voltage-free switches mentioned in /hardware's readme. If I'm understanding the specs of that strip right (i.e., it needs a signal high/low to modulate the power strip), I'd need to hook into the high-current relay instead and modulate that.

Any tips as to which plug that is  and how to address it? Am not an EE by training, so inspecting the trace didn't actually do much for me.

@thatch for viz -- saw you helped put this together originally and are recently active on GH, so would be super appreciative of any help here. Thanks for your work on this to date, and hope all's well!

thatch, 2025-01-15:
The 3v listed voltage makes me wonder if they are avoiding the diode drop by doing something slightly more clever; I don't think it would be a mosfet as ideal diode due to the high end voltage listed; perhaps it's a circuit like:

```
IN+ --- R ---+----------+
             |          |
         [rev zener]    R
             |        [opto led]
             |          |
IN- ---------+----------+
```

then I'd expect around 30mA, still suitable for any of those listed headers

bklebke, 2025-01-15:
Thank you - deeply appreciate the quick and thoughtful response!

It looks like we're using J1, J2, and J4 right now - for on/offbuttons and a buzzer, respectively

J7, J3/5, and J8 are all free. From http://www.digital-loggers.com/iotfaqs.html they claim 0.2ma to trigger, which seems low - but all are able to do this.

Assuming I move the connectors to pins 1/3 on J7, is the config update as simple as modifying

enable_output = Relay:ActiveHigh:29, Relay:ActiveHigh:31

to

enable_output = Relay:ActiveHigh:40
?

I know it's technically not a relay on J7, but we'd need a constant signal so I'm not sure the button or buzzer types are appropriate.

Thanks again!

bklebke, 2025-01-15:
Fantastic, was able to get it up and running with your help. Will add documentation for this going forward in case others use a similar approach. Really really appreciate your help!

Closed 2025-01-15.

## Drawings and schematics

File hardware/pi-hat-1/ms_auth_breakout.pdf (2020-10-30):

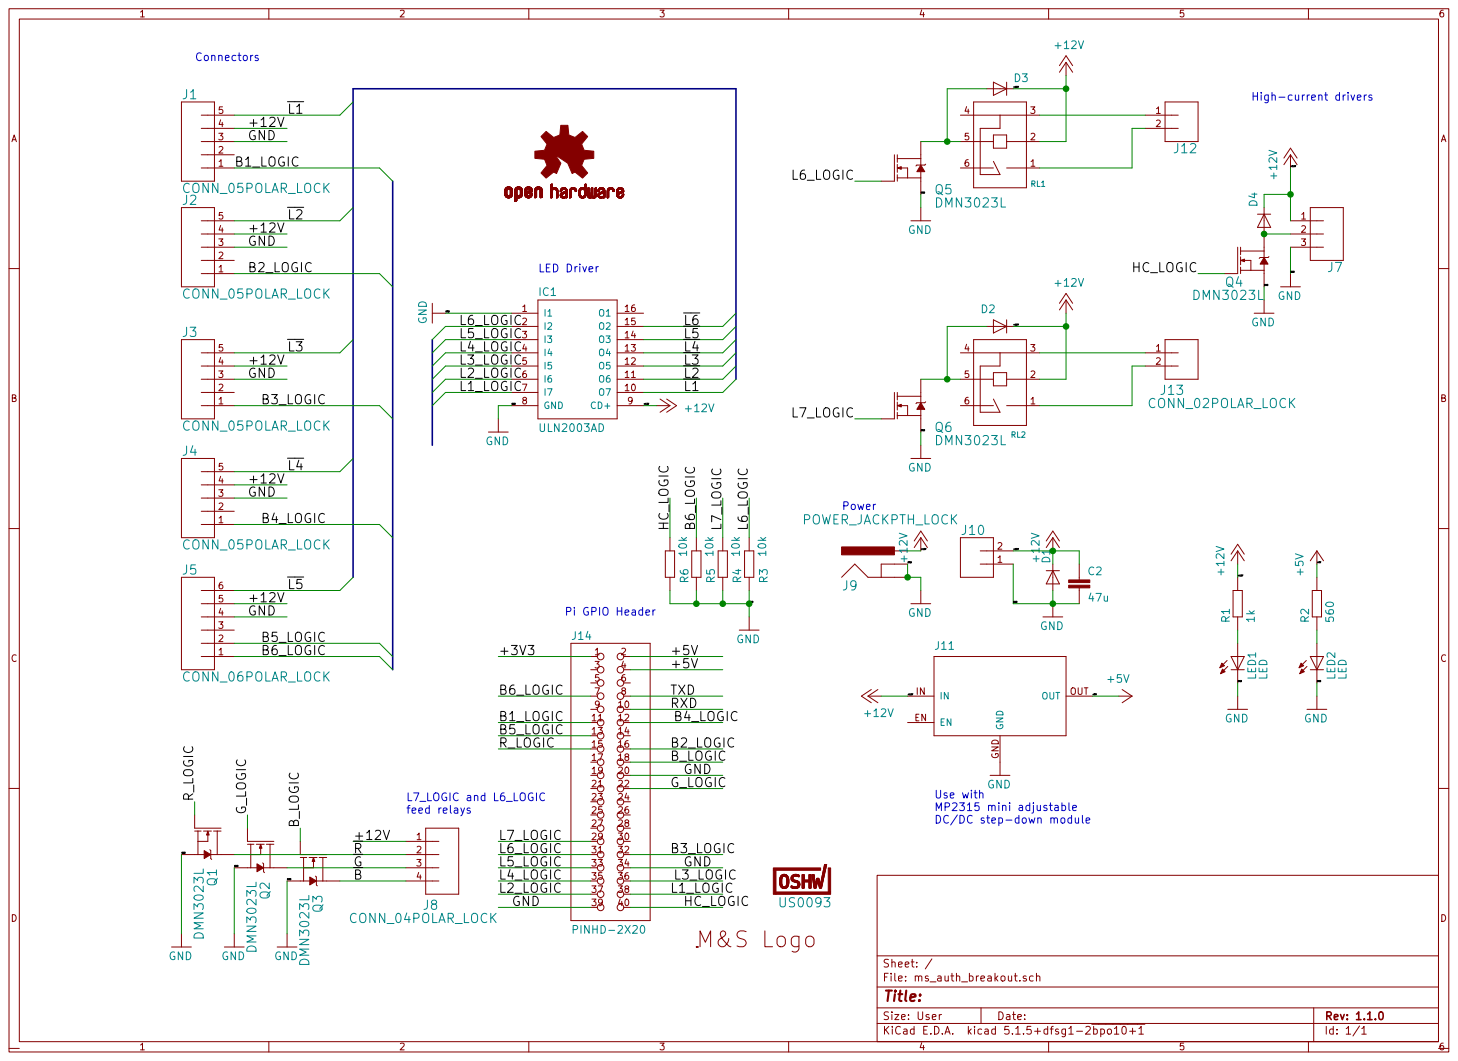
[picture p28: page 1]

+5V Use with MP2315 mini adjustable

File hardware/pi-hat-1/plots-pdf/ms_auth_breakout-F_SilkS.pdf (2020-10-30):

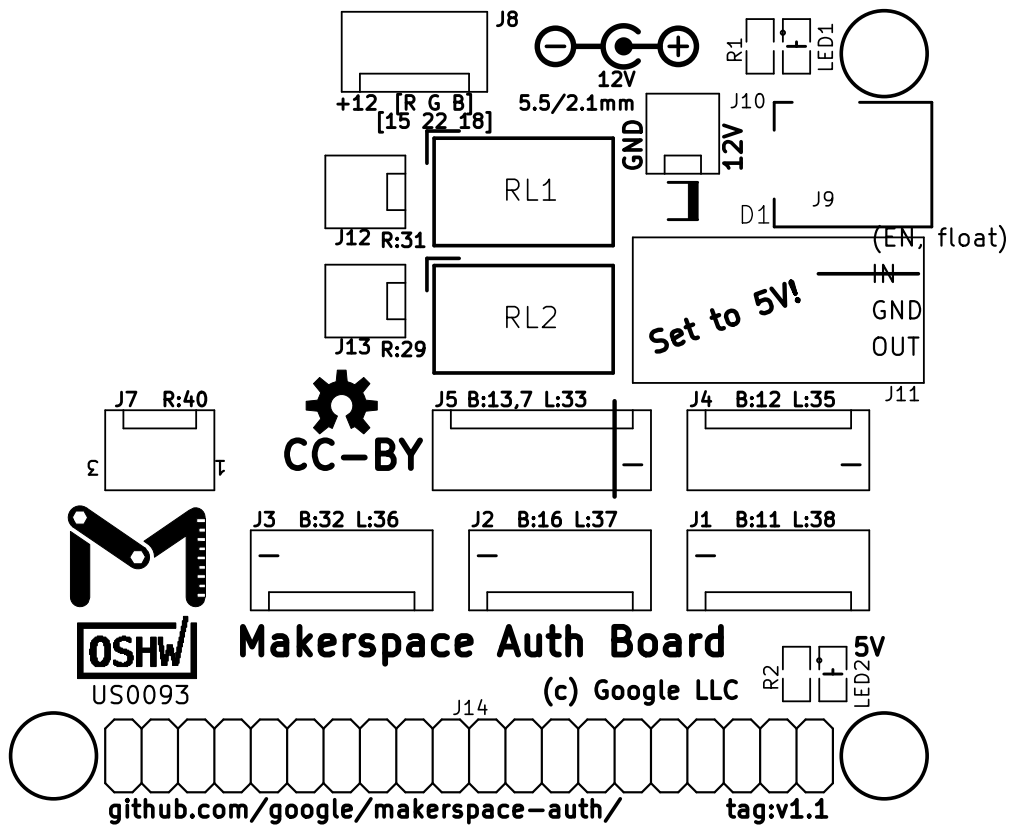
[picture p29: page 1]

(EN, float) OUT GND

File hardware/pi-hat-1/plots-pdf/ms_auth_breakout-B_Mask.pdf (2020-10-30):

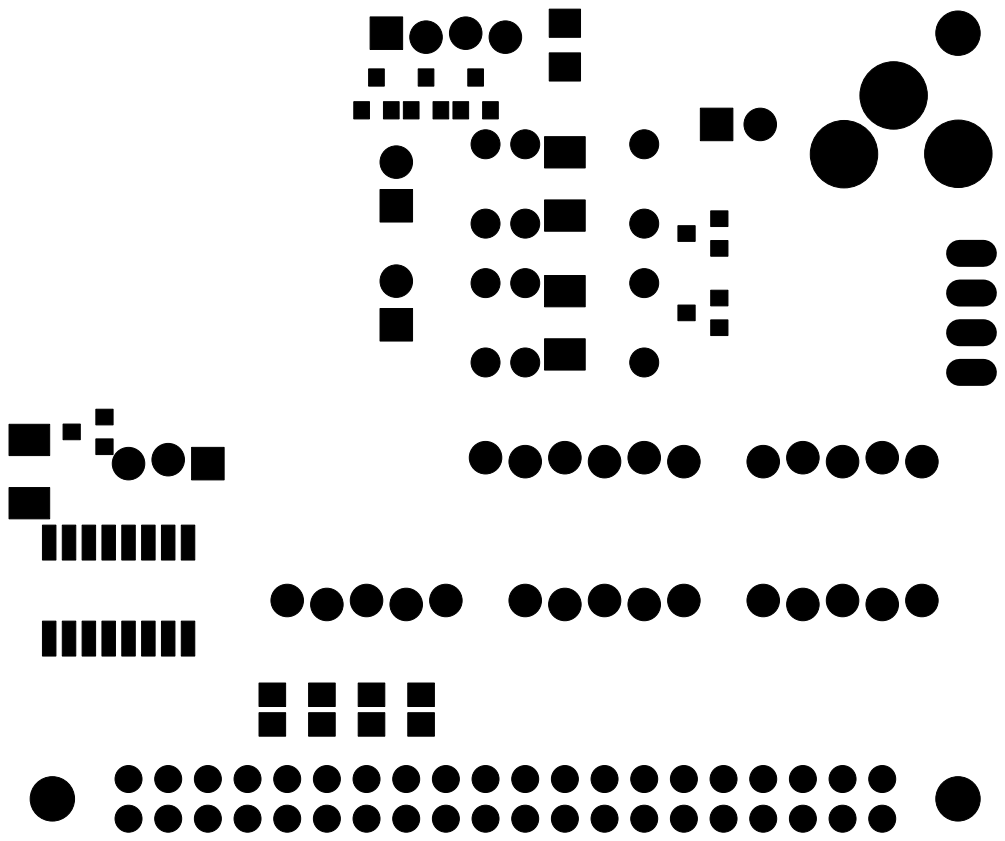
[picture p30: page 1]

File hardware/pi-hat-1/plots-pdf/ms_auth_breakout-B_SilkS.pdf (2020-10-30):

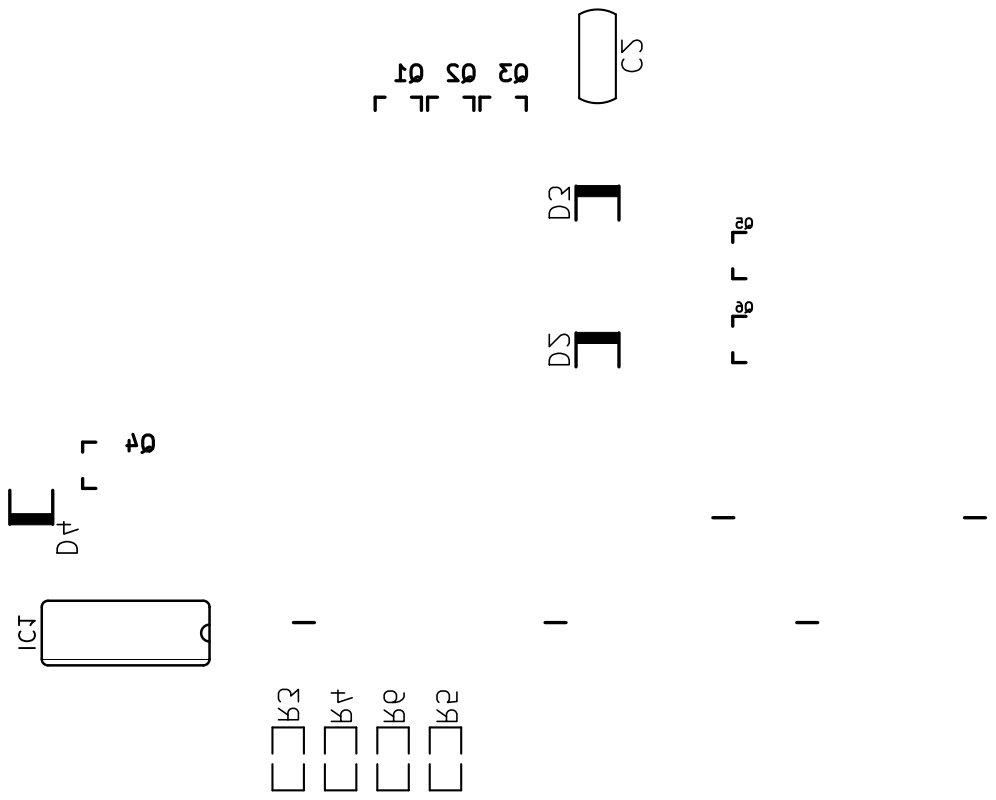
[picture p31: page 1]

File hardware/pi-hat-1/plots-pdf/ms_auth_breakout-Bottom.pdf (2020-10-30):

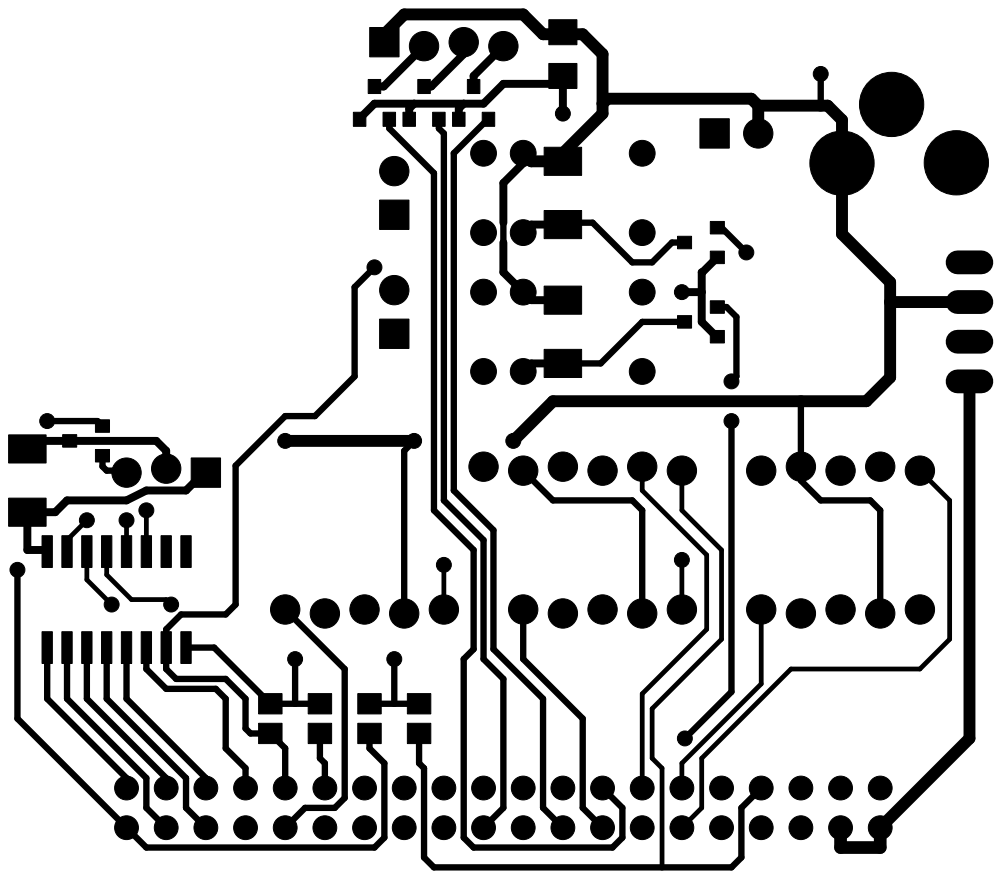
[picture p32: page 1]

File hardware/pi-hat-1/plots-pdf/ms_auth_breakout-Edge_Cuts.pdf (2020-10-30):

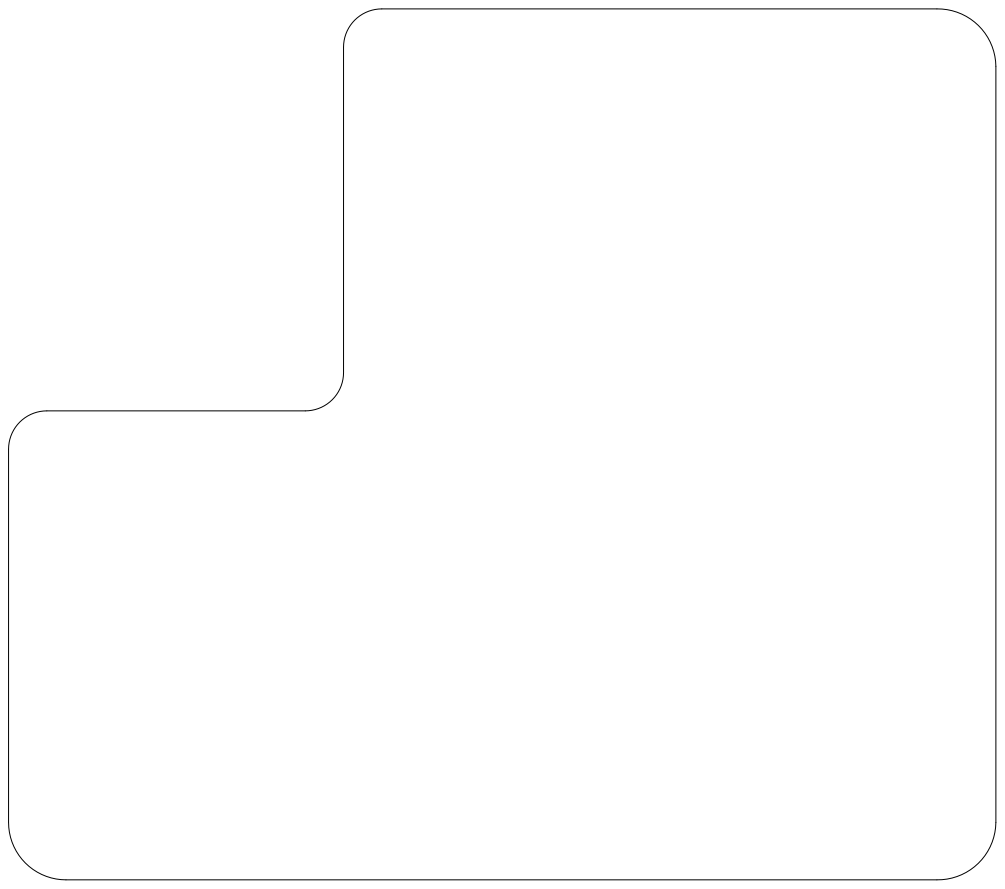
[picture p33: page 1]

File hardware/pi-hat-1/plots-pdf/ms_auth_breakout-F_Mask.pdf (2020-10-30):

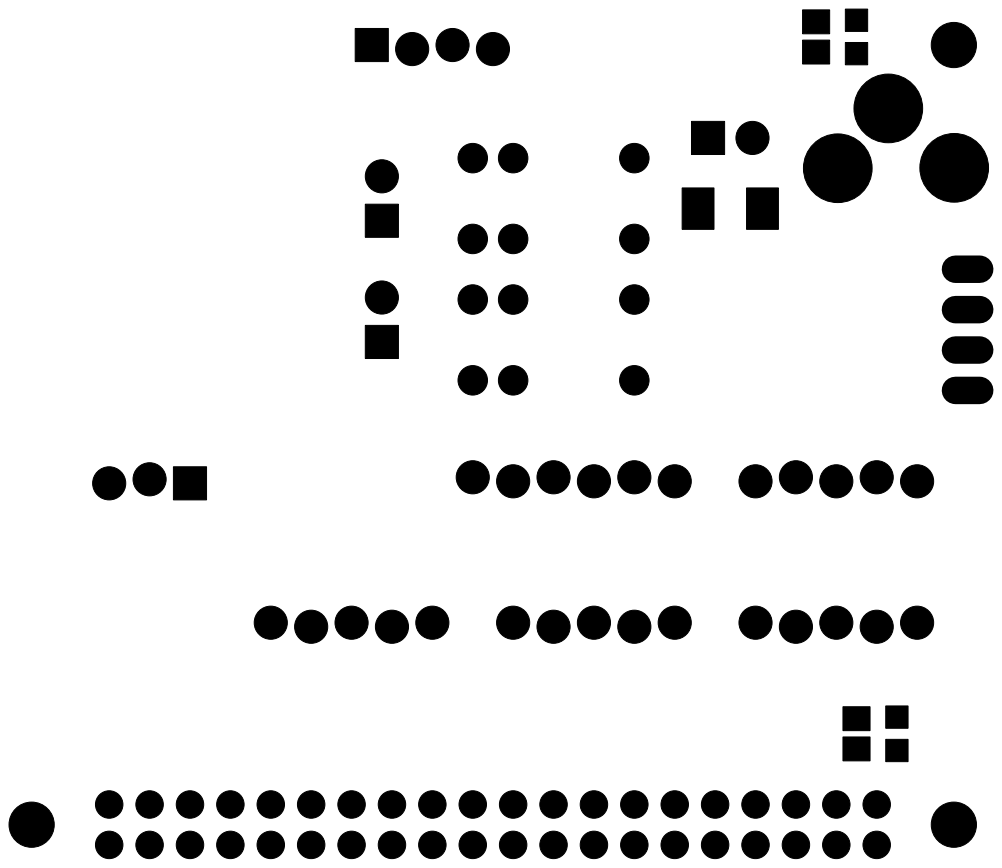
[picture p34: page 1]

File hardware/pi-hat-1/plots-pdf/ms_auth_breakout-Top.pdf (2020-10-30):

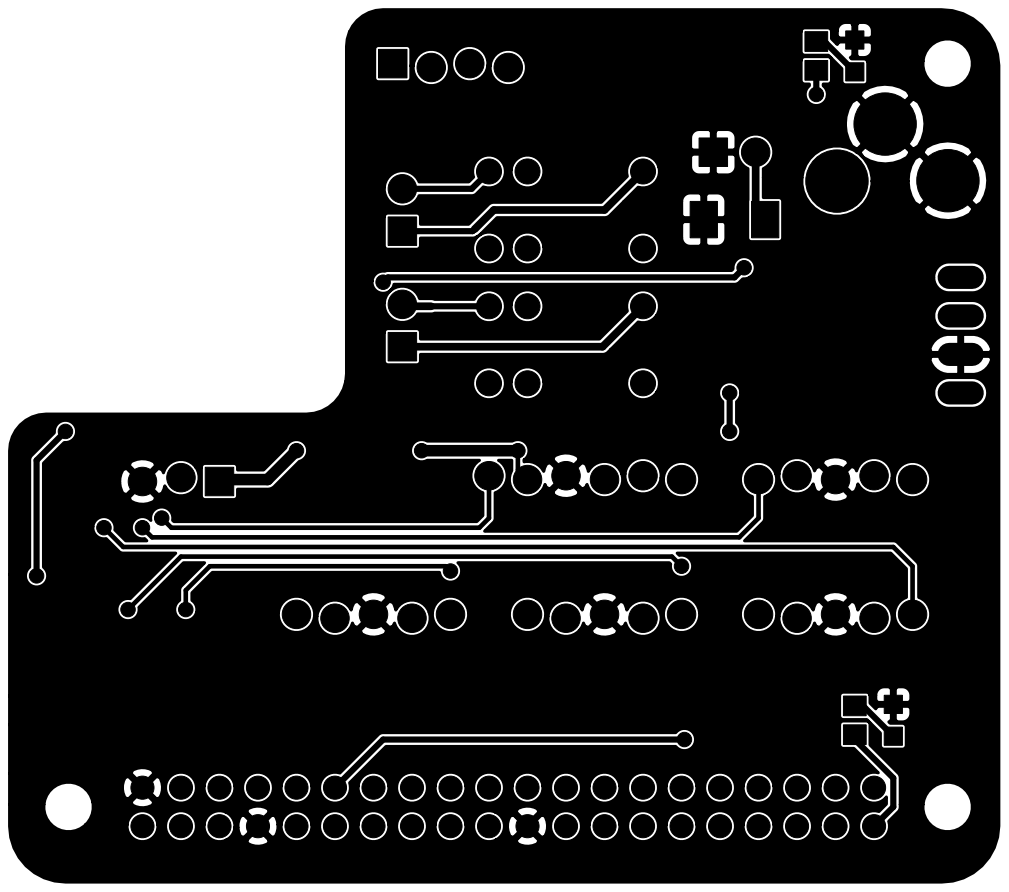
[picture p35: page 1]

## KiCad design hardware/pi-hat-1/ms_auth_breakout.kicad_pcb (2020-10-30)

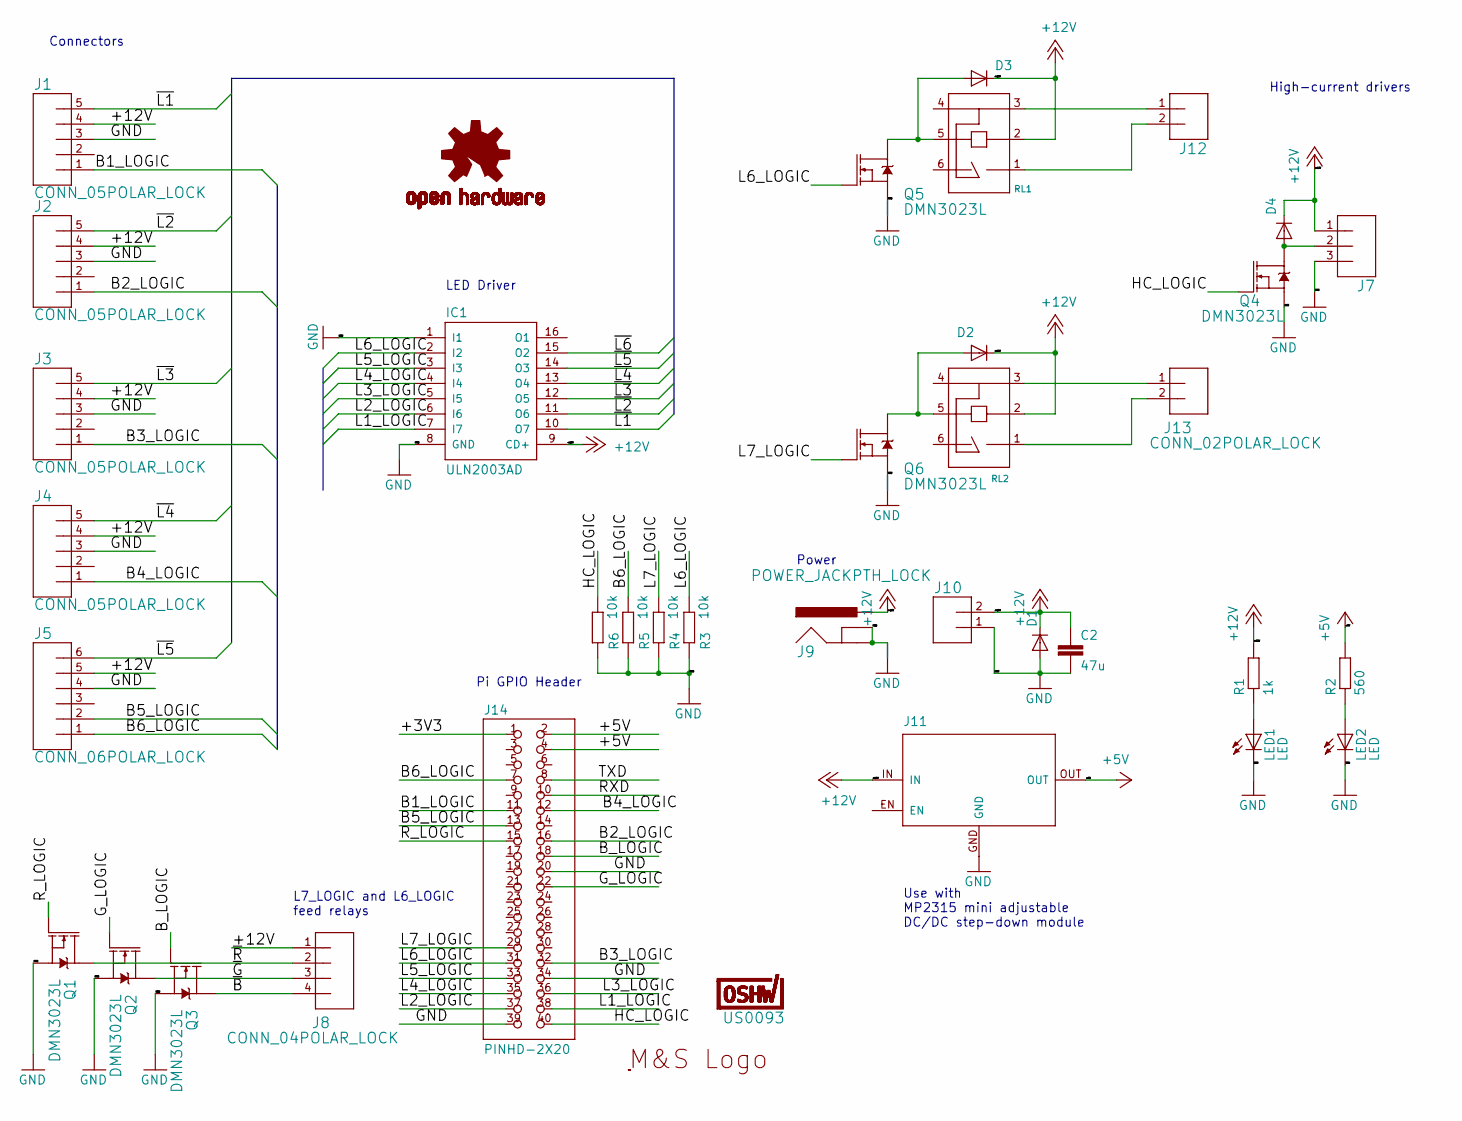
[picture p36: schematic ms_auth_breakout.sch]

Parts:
C2: 47u; C1206
D1, D2, D3, D4: DIODE-DO-214AC; DO-214AC; MPN SS14CT-ND
IC1: ULN2003AD; SO16; MPN ULN2003ADR
J1, J2, J3, J4: CONN_05POLAR_LOCK; MOLEX-1X5_LOCK; MPN 22-23-2051
J5: CONN_06POLAR_LOCK; MOLEX-1X6_LOCK; MPN 22-23-2061
J7: CONN_03POLAR_LOCK; MOLEX-1X3_LOCK; MPN 22-23-2031
J8: CONN_04POLAR_LOCK; MOLEX-1X4_LOCK; MPN 22-23-2041
J9: POWER_JACKPTH_LOCK; POWER_JACK_PTH_LOCK; MPN 694106301002
J10, J12, J13: CONN_02POLAR_LOCK; MOLEX-1X2_LOCK; MPN 22-23-2021
J11: BUCK_MODULEHORIZONTAL; BUCK_HORIZONTAL; MPN mp2315-module
J14: PINHD-2X20; 2X20; MPN SFH11-PBPC-D20-ST-BK
LED1, LED2: LED; CHIPLED_0805; MPN LG R971-KN-1
LOGO1: OSHW-LOGOM; OSHW-LOGO-M
Q1, Q2, Q3, Q4, Q5, Q6: DMN3023L; SOT23-3; MPN DMN3023L-7
R1: 1k; R0805
R2: 560; R0805
R3, R4, R5, R6: 10k; R0805
RL1, RL2: HFD23_SPDT; HFD23; MPN HFD23/012-1ZS
U$1: MS_LOGO; MS_LOGO_VECTOR
U$2: US0093; CERT-SMALL-SILK

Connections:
+5V: J11.OUT, J14.2, J14.4, R2.2
+12V: C2.1, D1.C, D2.C, D3.C, D4.C, IC1.9 (CD+), J1.4, J2.4, J3.4, J4.4, J5.5, J7.1, J8.1, J9.PWR, J10.2, J11.IN, R1.2, RL1.2, RL2.2
/+3V3: J14.1
/B1_LOGIC: J1.1, J14.11
/B2_LOGIC: J2.1, J14.16
/B3_LOGIC: J3.1, J14.32
/B4_LOGIC: J4.1, J14.12
/B5_LOGIC: J5.2, J14.13
/B6_LOGIC: J5.1, J14.7, R5.2
/B_LOGIC: J14.18, Q3.1 (G)
/G_LOGIC: J14.22, Q2.1 (G)
/HC_LOGIC: J14.40, Q4.1 (G), R6.2
/L1_LOGIC: IC1.7 (I7), J14.38
/L2_LOGIC: IC1.6 (I6), J14.37
/L3_LOGIC: IC1.5 (I5), J14.36
/L4_LOGIC: IC1.4 (I4), J14.35
/L5_LOGIC: IC1.3 (I3), J14.33
/L6_LOGIC: IC1.2 (I2), J14.31, Q5.1 (G), R3.2
/L7_LOGIC: J14.29, Q6.1 (G), R4.2
/RXD: J14.10
/R_LOGIC: J14.15, Q1.1 (G)
/TXD: J14.8
/~B: J8.4, Q3.3 (D)
/~G: J8.3, Q2.3 (D)
/~L1: IC1.10 (O7), J1.5
/~L2: IC1.11 (O6), J2.5
/~L3: IC1.12 (O5), J3.5
/~L4: IC1.13 (O4), J4.5
/~L5: IC1.14 (O3), J5.6
/~L6: IC1.15 (O2)
/~R: J8.2, Q1.3 (D)
GND: C2.2, D1.A, IC1.1 (I1), IC1.8 (GND), J1.3, J2.3, J3.3, J4.3, J5.4, J7.3, J9.GND, J9.GNDBREAK, J10.1, J11.GND, J14.20, J14.34, J14.39, LED1.C, LED2.C, Q1.2 (S), Q2.2 (S), Q3.2 (S), Q4.2 (S), Q5.2 (S), Q6.2 (S), R3.1, R4.1, R5.1, R6.1
unnamed: D2.A, Q6.3 (D), RL2.5
unnamed: D3.A, Q5.3 (D), RL1.5
unnamed: D4.A, J7.2, Q4.3 (D)
unnamed: J12.1, RL1.3
unnamed: J12.2, RL1.1
unnamed: J13.1, RL2.3
unnamed: J13.2, RL2.1
unnamed: LED1.A, R1.1
unnamed: LED2.A, R2.1

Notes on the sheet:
Pi GPIO Header
LED Driver
Connectors
Power
High-current drivers
L7_LOGIC and L6_LOGIC feed relays
Use with MP2315 mini adjustable DC/DC step-down module

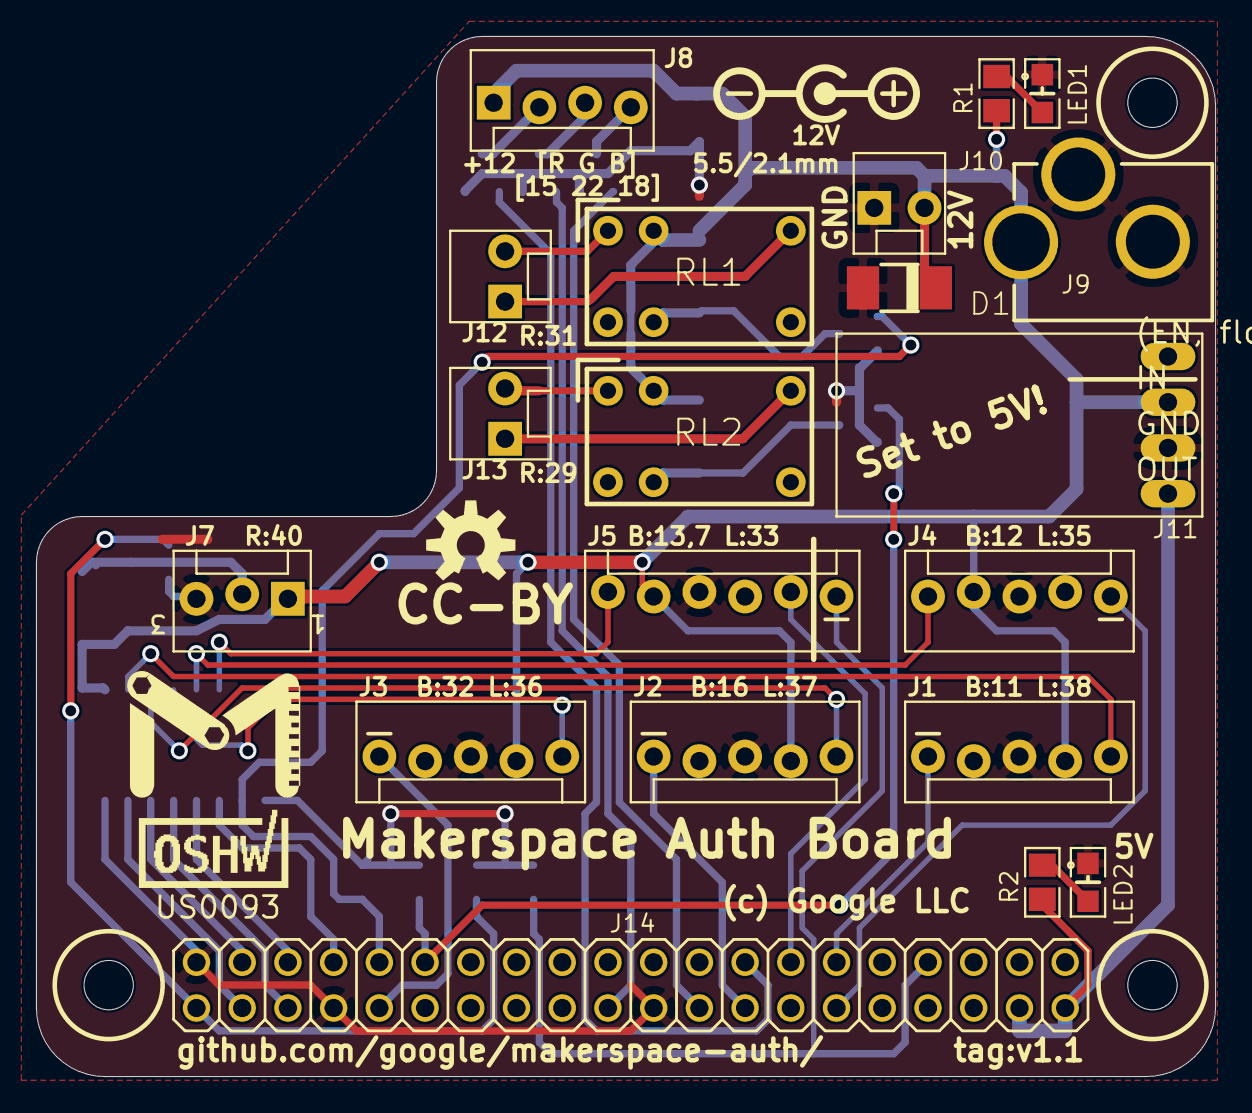
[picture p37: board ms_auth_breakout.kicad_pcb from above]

Board: 2 copper layers, 65.5 x 57.8 mm, 41 parts (0 on the bottom side), 37 nets.

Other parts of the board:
@HOLE0, @HOLE1, @HOLE2: (no value)

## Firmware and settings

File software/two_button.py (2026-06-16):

#!/usr/bin/python
#
# Copyright 2017 Google Inc. All Rights Reserved.
#
# Licensed under the Apache License, Version 2.0 (the "License");
# you may not use this file except in compliance with the License.
# You may obtain a copy of the License at
#
#     http://www.apache.org/licenses/LICENSE-2.0
#
# Unless required by applicable law or agreed to in writing, software
# distributed under the License is distributed on an "AS-IS" BASIS,
# WITHOUT WARRANTIES OR CONDITIONS OF ANY KIND, either express or implied.
# See the License for the specific language governing permissions and
# limitations under the License.

"""Example using two buttons for "on" and "off" once badged.

"""
from __future__ import print_function

import os
import shlex
import subprocess
import sys

from authbox.api import BaseDispatcher, MultiProxy, split_escaped
from authbox.config import Config
from authbox.timer import Timer

DEVNULL = open("/dev/null", "r+")


class Dispatcher(BaseDispatcher):
    def __init__(self, config):
        super(Dispatcher, self).__init__(config)

        self.authorized = False
        self.load_config_object("on_button", on_down=self.on_button_down)
        self.load_config_object("off_button", on_down=self.abort)
        self.load_config_object("badge_reader", on_scan=self.badge_scan)
        self.load_config_object("enable_output")
        self.load_config_object("buzzer")

        # Custom loading for enable_output to support delay
        enable_outputs_config = list(
            split_escaped(self.config.get("pins", "enable_output"), preserve=True)
        )

        self.delay_map = self._load_delay_map()

        self.outputs = []
        if isinstance(self.enable_output, MultiProxy):
            objs = self.enable_output.objs
        else:
            objs = [self.enable_output]

        for i, obj in enumerate(objs):
            if i < len(enable_outputs_config):
                pin_str = enable_outputs_config[i].strip()
                delay = self.delay_map.get(pin_str, 0)
                self.outputs.append((obj, delay))
            else:
                self.outputs.append((obj, 0))

        self.warning_timer = Timer(self.event_queue, "warning_timer", self.warning)
        self.expire_timer = Timer(self.event_queue, "expire_timer", self.abort)
        self.expecting_press_timer = Timer(
            self.event_queue, "expecting_press_timer", self.abort
        )

        self.timers = {}
        self.threads.extend(
            [self.warning_timer, self.expire_timer, self.expecting_press_timer]
        )

        for obj, delay in self.outputs:
            if delay > 0:
                timer_name = f"off_timer_{id(obj)}"
                # Lambda captures obj correctly if we use a default arg.
                timer = Timer(
                    self.event_queue,
                    timer_name,
                    lambda source, o=obj: self.delayed_off_generic(o),
                )
                self.timers[id(obj)] = (timer, delay)
                self.threads.append(timer)

        self.noise = None
        self.delayed_off_running = False
        self.running_timers_count = 0

    def _get_command_line(self, section, key, format_args):
        """Constructs a command line, safely.

        The value can contain {key}, {}, and {5} style interpolation:
          - {key} will be resolved in the config.get; those are considered safe and
            spaces will separate args.
          - {} works on each arg independently (probably not what you want).
          - {5} works fine.
        """
        value = self.config.get(section, key)
        pieces = shlex.split(value)
        return [p.format(*format_args) for p in pieces]

    def _load_delay_map(self):
        delay_map = {}
        try:
            delays_str = self.config.get("pins", "output_off_delay_seconds")
            delay_map = self._parse_delay_str(delays_str)
        except Exception:
            pass

        if not delay_map:
            try:
                delays_str = self.config.get("auth", "output_off_delay_seconds")
                delay_map = self._parse_delay_str(delays_str)
            except Exception:
                pass

        return delay_map

    def _parse_delay_str(self, delays_str):
        delay_map = {}
        if not delays_str:
            return delay_map
        delays_str = delays_str.replace("[", "").replace("]", "").strip()
        pairs = [p.strip() for p in delays_str.split(",")]
        for pair in pairs:
            if "=" in pair:
                k, v = pair.split("=")
                k = k.strip()
                v = v.strip()
                try:
                    # Use Config.parse_time to support suffixes
                    from authbox.config import Config

                    delay_map[k] = Config.parse_time(v)
                except Exception as e:
                    print("Error parsing delay for", k, v, e)
        return delay_map

    def badge_scan(self, badge_id):
        # Malicious badge "numbers" that contain spaces require this extra work.
        command = self._get_command_line("auth", "command", [badge_id])
        # TODO timeout
        # TODO test with missing command
        rc = subprocess.call(command)
        if rc == 0:
            self.buzzer.beep()
            self.authorized = True
            self.badge_id = badge_id
            self.expecting_press_timer.set(30)
            self.on_button.blink()
        else:
            self.off_button.blink(1)
            self.buzzer.beep()
            if self.noise:
                self.noise.kill()
            if self.config.get("sounds", "enable") == "1":
                sound_command = self._get_command_line(
                    "sounds", "command", [self.config.get("sounds", "sad_filename")]
                )
                self.noise = subprocess.Popen(
                    sound_command, stdin=DEVNULL, stdout=DEVNULL, stderr=DEVNULL
                )

    def on_button_down(self, source):
        print("Button down", source)
        if not self.authorized:
            if self.delayed_off_running:
                self.authorized = True
                self.delayed_off_running = False
                self.running_timers_count = 0
                for timer, _ in self.timers.values():
                    timer.cancel()
            else:
                self.off_button.blink(1)
                self.buzzer.beep()
                if self.noise:
                    self.noise.kill()
                if self.config.get("sounds", "enable") == "1":
                    sound_command = self._get_command_line(
                        "sounds", "command", [self.config.get("sounds", "sad_filename")]
                    )
                    self.noise = subprocess.Popen(
                        sound_command, stdin=DEVNULL, stdout=DEVNULL, stderr=DEVNULL
                    )
                return
        self.expecting_press_timer.cancel()
        self.on_button.on()
        self.enable_output.on()
        for timer, _ in self.timers.values():
            timer.cancel()
        self.buzzer.off()
        self.warning_timer.cancel()
        self.expire_timer.cancel()
        # TODO use extend time if we were already enabled, and run its command for
        # logging.
        # N.b. Duration (or extend) includes the warning time.
        self.warning_timer.set(
            self.config.get_int_seconds("auth", "duration", "5m")
            - self.config.get_int_seconds("auth", "warning", "10s")
        )
        self.expire_timer.set(self.config.get_int_seconds("auth", "duration", "5m"))
        if self.noise:
            self.noise.kill()
            self.noise = None

    def abort(self, source):
        print("Abort", source)
        delayed_count = 0
        for obj, delay in self.outputs:
            if delay == 0:
                obj.off()
            else:
                timer, _ = self.timers.get(id(obj), (None, None))
                if timer:
                    timer.cancel()
                    timer.set(delay)
                    delayed_count += 1

        if delayed_count > 0:
            self.delayed_off_running = True
            self.running_timers_count = delayed_count

        if self.authorized:
            command = self._get_command_line("auth", "deauth_command", [self.badge_id])
            subprocess.call(command)
        self.off_button.blink(1)
        self.buzzer.beep()
        self.authorized = False
        self.warning_timer.cancel()
        self.expecting_press_timer.cancel()
        self.expire_timer.cancel()
        self.on_button.off()
        self.buzzer.off()
        if self.noise:
            self.noise.kill()
            self.noise = None

    def delayed_off_generic(self, obj):
        print("Delayed off generic", obj)
        obj.off()
        self.running_timers_count -= 1
        if self.running_timers_count <= 0:
            self.delayed_off_running = False
            self.running_timers_count = 0

    def warning(self, unused_source):
        self.buzzer.beepbeep()
        if self.config.get("sounds", "enable") == "1":
            sound_command = self._get_command_line(
                "sounds", "command", [self.config.get("sounds", "warning_filename")]
            )
            self.noise = subprocess.Popen(
                shlex.split(sound_command),
                stdin=DEVNULL,
                stdout=DEVNULL,
                stderr=DEVNULL,
            )
        self.on_button.blink()


def main(args):
    if not args:
        root = "~"
    else:
        root = args[0]

    config = Config(os.path.join(root, ".authboxrc"))
    Dispatcher(config).run_loop()


if __name__ == "__main__":
    main(sys.argv[1:])

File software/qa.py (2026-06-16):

#!/usr/bin/python
#
# Copyright 2018 Google Inc. All Rights Reserved.
#
# Licensed under the Apache License, Version 2.0 (the "License");
# you may not use this file except in compliance with the License.
# You may obtain a copy of the License at
#
#     http://www.apache.org/licenses/LICENSE-2.0
#
# Unless required by applicable law or agreed to in writing, software
# distributed under the License is distributed on an "AS-IS" BASIS,
# WITHOUT WARRANTIES OR CONDITIONS OF ANY KIND, either express or implied.
# See the License for the specific language governing permissions and
# limitations under the License.

"""Example to test all the buttons.

"""
from __future__ import print_function

import sys
import time

from authbox.api import BaseDispatcher
from authbox.config import Config
from authbox.timer import Timer

DEVNULL = open("/dev/null", "r+")


class Dispatcher(BaseDispatcher):
    def __init__(self, config):
        super(Dispatcher, self).__init__(config)

        for i in range(1, 6 + 1):
            self.load_config_object("j%d" % i, on_down=self.on_button_down)

        self.load_config_object("buzzer")
        self.load_config_object("relays")
        # This may be a MultiProxy, which makes this easier.
        self.relays.on()
        self.relay_value = True

        # Run fans for 10 seconds on startup
        self.relay_timer = Timer(self.event_queue, "relay_timer", self.toggle_relays)
        self.relay_toggle_interval = 10
        self.relay_timer.set(self.relay_toggle_interval)
        self.threads.extend([self.relay_timer])

    def on_button_down(self, source):
        print("Button down", source)
        self.buzzer.beep()

        source.on()
        time.sleep(0.3)
        source.off()

    def toggle_relays(self, source):
        print("Toggle relay", self.relay_value)
        if self.relay_value:
            self.relays.off()
            self.relay_value = False
        else:
            self.relays.on()
            self.relay_value = True
        self.relay_timer.set(self.relay_toggle_interval)


def main(args):
    if not args:
        config_filename = "qa.ini"
    else:
        config_filename = args[0]

    config = Config(config_filename)
    Dispatcher(config).run_loop()


if __name__ == "__main__":
    main(sys.argv[1:])

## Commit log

2017-01-24 Add first board, update readmes and gitignore
    [ms_auth_breakout.brd, ms_auth_breakout.sch]
2017-02-03 Large Structural Change
    Moved most classes/functions into auth_lib.py.
    Added Buzzer and PowerSwitch object classes.
    Added Docstrings.
    Replaced main.py with twoButtonExample.py.
    Added instance tracking to Button class.
2017-02-08 Board v0.2 sent to fab.
    This now has 5 button headers, a dedicated PowerSwitch Tail header, and
    a dedicated buzzer. Buck converter has been moved onboard, and we
    connect to a 3rd mounting hole for stability. Since there's room, add a
    barrel jack.
    This version includes the pin number on silkscreen next to each item.
    The 5-pin locking part isn't yet upstreamed to SparkFun's library.
    The vector logo in ms-logo.lbr isn't updated in the schematic.
    [ms_auth_breakout.brd, ms_auth_breakout.sch]
2017-02-08 Begin v0.3 of auth board
    Improve 12V trace routing down the middle; swap to vector logo.
    [ms_auth_breakout.brd, ms_auth_breakout.sch]
2017-03-10 Getting ready to order pi-hat-1 v0.3
    I re-routed this almost completely. The area in the middle now makes a bit
    more sense, and there's only one ground island that had to be reconnected.
    * Switched back to buck module
    * Found room for 6 button connectors again
    * Added discrete RGB LED driver
    * Added higher current output for inductive loads
    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
    [ms_auth_breakout.brd, ms_auth_breakout.sch]
2017-03-10 Reroute +12 line to avoid ground island
    [ms_auth_breakout.brd]
2017-03-10 Update pi-hat-1 board image
2017-03-16 Update readmes and board image
2017-04-20 Add snapshot of the bracket I use.
    [pibracket.stl, piclip.stl]
2017-04-29 Add client API and two-button example.
2017-04-29 Ensure everything works reasonably on Pi 3 hardware.
    This is a much more complete example that involves buzzer and various
    shell scripts for local logging.
    [api.py, badgereader_hid_keystroking.py, config.py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]
2017-05-28 Fix buck-module ENABLE pin location
2017-05-28 Add libs for relay and opto
2017-05-28 Rework board to add two relays.
    Also remove buzzer, change LED connector, and standardize on smaller
    freewheel diodes. Not quire ready for 0.4 cut; needs airwires routed
    for relays with solder jumpers.
    [ms_auth_breakout.brd, ms_auth_breakout.sch]
2017-06-07 pi-hat-1 v0.4 as-ordered
    (Forgot to route the relay connections though.)
    [ms_auth_breakout.brd, ms_auth_breakout.sch]
2017-06-13 Add rough BOM for v0.4
2018-01-17 Authboard change for v1.0
    - Remove SOP-4 optos (most test boards we assembled with relays)
    - Remove J6 (most test boards for laser need 3 outputs)
    - Swap SIP resistor for 4x discrete (easier to mass-produce without it)
    - Improve silkscreen around polarity and buck module
    - Add MPN/MFN to parts on board. (Should this go in schematic?)
    - Change J5 to support a 3-position switch, intended for marking
    ready/needs-maintenance/down
    - Leave some room for an OSH Cert number :)
    [ms_auth_breakout.brd, ms_auth_breakout.sch]
2018-01-18 Add relay MPN, OSH Certification mark
    [ms_auth_breakout.brd, ms_auth_breakout.sch]
2018-02-28 Update for 2018. Minor behavior changes.
    - button callback now includes self instead of config_name
    - Main loop prints traceback on exceptions
    - Single beep now available on buzzer
    [api.py, badgereader_hid_keystroking.py, config.py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]
2018-02-28 Add QA script to exercise all buttons/lights/relays
2018-02-28 Split out tonal buzzer (non-working)
    [two_button.py]
2018-02-28 Add enable for speaker-sounds, fix pins
    [two_button.py]
2018-03-06 Fix stack trace in gpio_buzzer.py:39
    Add 1-length tuple instead of bare integer to set_queue in on() and off()
    methods because that's what run_inner() expectes. Fixes the following error:
    File "/home/pi/makerspace-auth/software/authbox/api.py", line 122, in run
    self.run_inner()
    File "/home/pi/makerspace-auth/software/authbox/gpio_buzzer.py", line 39,
    in run_inner
    next_mode = item[0]
    [gpio_buzzer.py]
2018-03-06 Cancel warning buzzer when extending time with green button
    [two_button.py]
2018-03-08 Call GPI.cleanup() on exit to turn off lights and relays.
2018-03-08 Explicitly set GPIO outputs to initial state on startup.
    Code expects most GPIOs will output low when enabled on startup.
    This is the case after a hard reset, but it's possible GPIOs outputs
    were manually enabled and set high before software start. Setting
    them on startup ensures the pin state matches what the software
    expects. Most GPIOs are initialized low. ActiveLow Relay will be
    initialized high.
    [api.py, gpio_relay.py]
2018-05-16 Increase size of buckmodule drill
    [ms_auth_breakout.brd, ms_auth_breakout.sch]
2018-05-16 Rename JP1->J14, move some vias
    [ms_auth_breakout.brd, ms_auth_breakout.sch]
2018-05-16 Switch diode part number, add resistors, minor trace tweak
    [ms_auth_breakout.brd]
2018-05-16 Add Epilog docs
    [bracket_both.scad, bracket_both.stl, bracket_clip.scad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]
2018-05-16 Make one box mount slightly shorter, regen.
    This lets us cut the inner+outer on the same stock on a Mini 24.
    [one_box_mount_lib.scad]
2018-05-16 Update shelf to not require support
    This improves the hard support that didn't play nice with Cura's
    "concentric" solid layers, since it apparently doesn't do bridging.
    [bracket_both.scad, bracket_both.stl, bracket_clip.stl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]
2018-05-16 Add templates for sides and lid
    [one_box_mount_front_hole_template.scad, one_box_mount_lib.scad, one_box_mount_lid_hole_template.scad]
2018-05-16 Add letters for easier plate alignment
    [one_box_mount_lib.scad]
2018-05-16 Add wiring help
2018-05-16 Add plate with both for better lasercutting
    [one_box_mount_both.scad]
2018-05-16 Round slots for easier cnc routing
    [one_box_mount_lib.scad]
2018-05-16 Regen plates
    [one_box_mount_both.dxf]
2018-05-18 doc/bug: Fixing 404 errors in docs
    Recent changes to the docs were using incorrect filenames in the
    documentation (missing the `.md` file extention which is required for
    files beyond `README.md` as the default in a directory).
    doc: Updating main README.md, removing stale data
    Previously the main README.md in the project referenced a sample python
    server which is no longer a part of the project. Additionally, there is
    now a more clearly codified location for documentation in the project.
2018-10-30 Avoid commit issues with sample credential files
    The file `sample_auth_check.sh` refers to two files which should not be
    kept in revision control:
    - `authorized.txt`
    - `logs.txt`
    This addition to `.gitignore` keeps those files from accidentally being
    commited.
2019-09-20 device: Wiegand badge reader support
    This commit provides support for [Wiegand][1] style badge readers. It has
    been tested with a number of EM4100 style readers and has been used in
    production for a number of months without issue.
    The wiring for a badge reader requires two data GPIO pins as input.
    These pins within the Wiegand protocol are "D0" and "D1" respectively.
    Normally, these pins are pulled high (generally to 5v). They perform
    differential signalling through pulling D0 low to represent a "0" and
    pulling D1 low to represent a "1".
    This introduces some challenges as most of the connectors have only a
    single raw GPIO input. In practice, this has been used with J5
    consuming the B5_L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
    [api.py, badgereader_wiegand_gpio.py, fake_gpio_for_testing.py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]
2019-09-20 contrib: Systemd Unit
    Setup of a contrib directory and a corresponding systemd unit to handle
    startup of makerspace auth on the Raspberry Pi.
2019-11-14 Fix broken test_badgereader_wiegand_gpio.py unit test
    [test_badgereader_wiegand_gpio.py]
2019-11-18 Speed up tests drastically, cover timer
2019-11-18 Fix tests on 2.7
    [test_gpio_button.py]
2019-11-21 Add Button.blink(count=0) to blink a finite number of times.
    Can be used for visual confirmation of an action or for blinking out an
    error code when something goes wrong.
    [fake_gpio_for_testing.py, gpio_button.py, test_gpio_button.py]
2019-11-21 Fix docstring indentation after Python Black reformat
    Black changed the indent from 2 to 4 spaces but it doesn't seem
    to handle docstring indentation at all.
    [badgereader_hid_keystroking.py, badgereader_wiegand_gpio.py, config.py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]
2019-11-21 Blink red light once if badge rejected or green button pushed when not authed
    Provides visual confirmation in addition to hearing the beep. Useful in
    noisy environments or if the buzzer is not installed.
    [two_button.py]
2019-11-22 Metadata changes
    - build universal (py2/py3) wheel
    - move coverage args to setup.cfg
    - add python_requires
2020-10-13 Replace Eagle design files with KiCad counterparts
    [ms_auth_breakout.brd, ms_auth_breakout.kicad_pcb, ms_auth_breakout.sch]
2020-10-13 Add PDF with schematic
2020-10-13 Replace existing BOM with the one generated from KiCad
    [ms_auth_breakout.csv]
2020-10-30 Add generated gerber files
    [ms_auth_breakout-B_Adhes.gbr, ms_auth_breakout-B_CrtYd.gbr, ms_auth_breakout-B_Fab.gbr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]
2020-10-30 Add PDF plots of copper layers and silkscreen markings
2024-04-17 Explicitely enable input pull-ups for button GPIO
2024-04-17 Add filter on button pressed to eliminae spurious signals and de-bounce
2024-04-17 Add beep and blink on press of abort button + immediately turn off the output
2024-04-27 Cancel `expire_timer` on abort
    If a user triggers abort using the `off_button`, `expire_timer` is currently still running. In these cases, the authbox will beep after the expiration time even if the authbox is no longer authorized.
    This change fixes this bug by canceling `expire_timer` in `abort`.
    [two_button.py]
2025-01-16 Create readme.md
    Added instructions for using the DLI IoT relay with the makerspace-auth
2025-03-04 Update remaining tests to run on raspberry pi
2026-03-25 Run lint/format across all files
    * Update the makefile to run them against all python files.
    * Fix syntax error in requirements_dev.txt (trailing period).
    * Update flake8 to v5.
    * Fix broken imports in unit tests
    * Run `make format` to get all files into a lint-clean state in preparation for future work.
    * Fix errors called out by `make lint`
    Fixes #59
    Tested:
    ```
    make setup
    python -m unittest
    make format
    make lint
    ```
    [api.py, badgereader_hid_keystroking.py, badgereader_wiegand_gpio.py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]
2026-06-16 Implement delayed-off support
    This allows each output pin to have a configured delay between the abort
    button being pressed and the pin being disabled. This supports scenarios
    such as keeping ventilation on longer after a tool has been deactivated.
    * Added unit tests for delayed off and reauth during delay timer. All
    tests pass
    * Physical hardware: confirmed that previous config file (with no
    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
2026-06-16 Avoid authing incorrectly on HTTP 302 redirect
    The sample & common way of verifying a specific user is authenticated
    is to use curl to check if a certain http query completes correctly.
    The -f or --fail flag passed to curl ensures zero vs non zero exit code
    based on http code.
    Unfortunately there is a corner case where a http redirect (302 status code)
    is by default not followed by curl AND it returns a zero exit code,
    accidentally considering any badge swipe valid.
    This is especially problematic as many cloud services, including AppEngine
    have set up an automatic redirect from http to https, making it so that
    a typo of http instead of https might accidentally make any badge swipe
    authent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

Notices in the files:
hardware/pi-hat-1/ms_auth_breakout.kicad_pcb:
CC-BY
